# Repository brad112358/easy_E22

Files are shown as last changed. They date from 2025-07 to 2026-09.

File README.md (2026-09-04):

# Easy DIY E22 NRF52840 Build Instructions #

This project provides build instructions and 3D print files for a
basic but powerful DIY Meshtastic node with the following features:

- Pocket sized
- Battery powered, ~40 hour run time (Up to 2 weeks with double 18650 version)
- ~1 watt maximum output on internal battery power
- ~2 watt maximum output on USB power
- Based on two easy-to-obtain COTS modules
- Relatively easy assembly and soldering with no custom PCB required
- Optional GPS, OLED display, and Rotary encoder can be added for standalone operation

The castellated edge connections on the E22 module, along with the pin
assignment flexibility of the NRF52 MCU, allow most signals to pass
between boards with no wiring.  Just careful positioning, a little
solder, and three header pins connect all signals.  Point-to-point
wiring is used only for power and peripherals.

The E22 gives this node outstanding performance in a compact package
with longer range than most commercially available pocket nodes.
The hinged and swiveling antenna matches the physical design of the
node, shielding the battery power switch from accidental bumps.  This
node works well when folded, yet makes no compromises when
straightened up at your destination.

The core of this build can also be used in solar nodes; see the note in
step 11 and the techincal notes at the end.

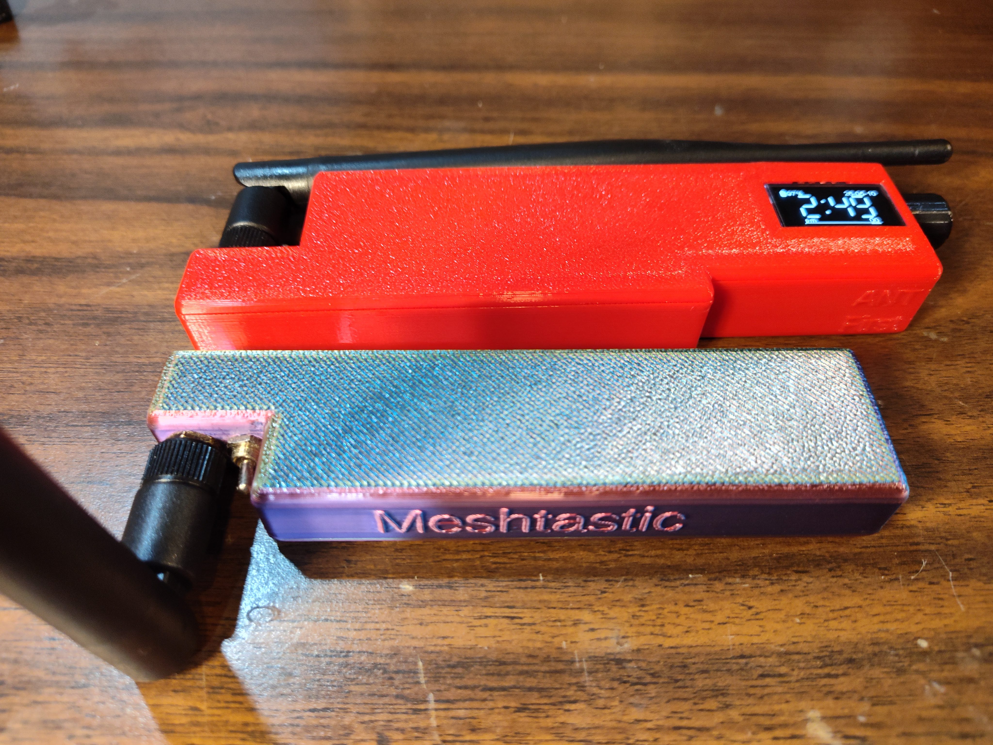
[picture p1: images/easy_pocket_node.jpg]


## Target audience

These instructions assume you have basic electronics soldering
equipment, supplies and tools, and are reasonably competent at
soldering surface mount and thru-hole PCBs.  If you have no experience
soldering, don't give up; you can probably learn to solder in a few
hours.  There are plenty of tutorial videos out there.  But don't do
your early practice on this project.

Similarly, it's best if you are familiar with other Meshtastic nodes
as this is not an introduction to Meshtastic.

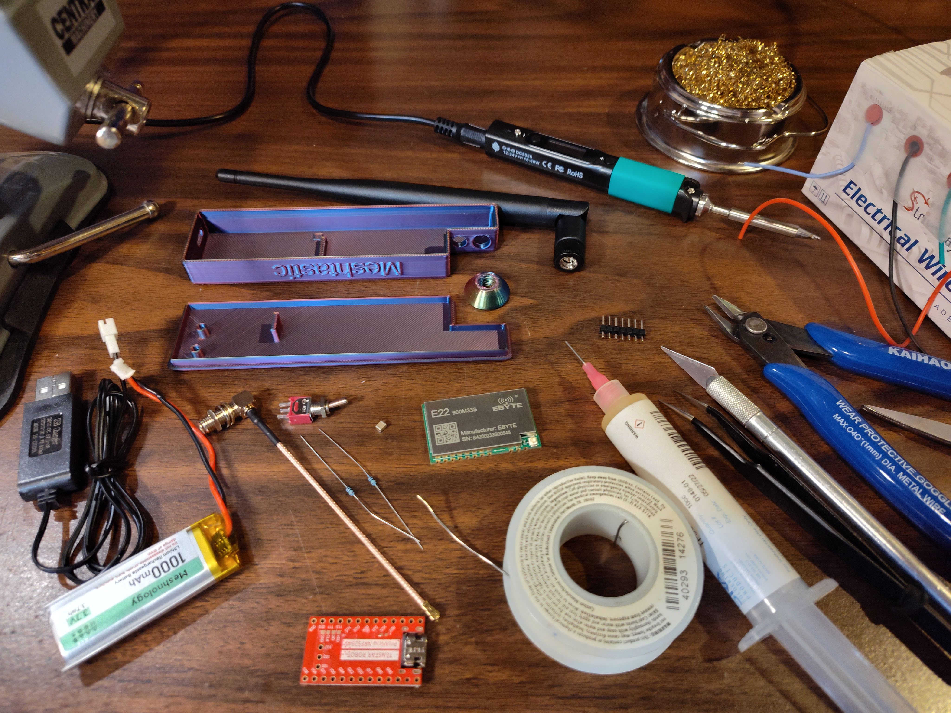
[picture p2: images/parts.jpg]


## Parts list:

Note: Product links are examples of components with the required
specifications and do not imply a recommendation of a specific part or
supplier.  These are not affiliate links.

- "Pro Micro compatible" NRF52840 dev module

    Such as the [Teyleten](https://www.amazon.com/dp/B0CYLNZ6V4), [Tenstar Robot](https://www.aliexpress.us/item/3256807958420169.html).
    Some of these can be found for less than $3 each.

- Ebyte E22 900M33S LoRa module

    Usually $15-20, available from [Amazon](https://www.amazon.com/868MHz-Wireless-E22-900M33S-Distance-Transceiver/dp/B0CZNHX91T) or [AliExpress](https://www.aliexpress.us/item/3256806595412116.html).
    
- 1000mAh LiPo cell with protection board or Li-ion 18650 cells

    The 50mm x 20mm x 10mm cells from
    [Amazon](https://www.amazon.com/dp/B0F1FM58ZW) or
    [AliExpress](https://www.aliexpress.us/item/3256802548578153.html)
    fits the smallest case design.

    Smaller cells can still provide useful battery life, but be sure
    they are capable of over 1 amp output without significant voltage
    drop.  Higher C cells will produce slightly higher RF output.
    You may also want a
    matching JST PH 2.0 socket like this one from
    [AliExpress](https://www.aliexpress.us/item/3256802377876396.html).
    
    You could try a [pre-made protected 18650 battery pack](https://www.amazon.com/GYMIN-Rechargeable-B0143KH9KG-18650-1s1p/dp/B0FRMR4ZHD).
    However, Amazon may not be the best source for high quality 18650 cells; so
    purchasing 18650 cells elsewhere is recommended if you want the
    best battery life.  You can use protected cells or, you can build
    your own battery pack with a [protection circuit](https://www.amazon.com/dp/B07W75BQWW) (recommended if
    you have experience building battery packs using a spot welder).

- Mini micro 3-pin SPDT toggle switch

    The battery switch needs to be smaller than is common; I used
    this one from
    [Amazon](https://www.amazon.com/dp/B075RDYMQQ) which is 8.2mm x 5.1mm
    and just fits.

- 915/868 MHz Antenna

    A high-quality hinged dipole fits and works well.
    
    Unfortunately, three out of three different brands I purchased
    from Amazon did not come close to high quality, and two of the
    three seemed to be less efficient multi-band antennas.
    
    The one that came with my Station G2 was close, needing only a
    slightly longer element to bring the resonant frequency down a bit
    from ~960 MHz.  The result looks very good now on the VNA.
    
    The ALFA Network ARS-915P from
    [ROKLAND](https://store.rokland.com/collections/all-helium-antennnas/products/alfa-network-ars-915pr-2-dbi-sma-male-915-mhz-antenna-with-90-elbow-for-t-beam-t-echo-lora32)
    Should be good quality for US use.

    When choosing antennas, be aware of the difference between SMA and
    RP-SMA.  It is, unfortunately, possible to attach an RP-SMA
    antenna to an SMA jack, but there will be no electrical connection,
    and you may damage the E22.  Always make sure you see a pin on
    one end or the other when connecting.

- SMA female right-angle 10 or 15cm Pigtail

    Like these from [Amazon](https://www.amazon.com/dp/B0F1R1FHK6)
    10cm may not be quite enough for the 2 18650 version of the case.
    
- Wire

    22-24 AWG stranded silicone wire is recommended for power
    connections to reduce voltage drop and keep RF power output up to
    spec.  30 AWG silicone wire works well for connecting the optional
    peripherals.

- Two battery sensing voltage divider resistors

    Almost any pair of the same value, axial-lead resistors will work to
    divide the battery voltage in half so that it can be measured
    safely by the ADC.
    10K - 1M ohm is recommended, as lower values may impact battery life.
    1/4 - 1/8 watt will work, but 1/8 watt is easier to fit.
    1% recommended, but up to 10% will work.
    You may need to adjust the ADC multiplier override ratio for
    accurate battery voltage readings, especially if you don't use 1%
    tolerance or choose a higher resistance than recommended.

- Common 2.54 mm pin header

    These usually come with the NRF52840 board.
    
- Heat-resistant insulating tape

    Every workbench should have a roll of this 
    [Stuff](https://www.amazon.com/ELEGOO-Polyimide-Temperature-Resistant-Multi-Sized/dp/B072Z92QZ2).
    Often called Kapton tape.

- Optional low power GPS module

    GPS modules only need power, ground, and two serial connections.
    [This one](https://www.amazon.com/dp/B09LQDG1HY) is relatively low
    power, fits well and has a small active antenna which fits well in
    the case.
    
- Optional passive buzzer/speaker

    A passive buzzer can be installed for (quiet) alert sounds
    and input feedback.
    [These](https://www.amazon.com/dp/B08MDNLDSV) were the lowest
    profile I could find and they just fit.

- Optional rotary encoder

    A small rotary encoder allows control via the Canned Message module.
    [These](https://www.amazon.com/dp/B07R8GKKX3) were the smallest I
    could find and fits well if the pins are bent carefully.
    
- Optional 1 inch OLED I2C display

    An OLED display is a good compromise with adequate visibility, low
    cost and reasonably low power.
    [These](https://www.amazon.com/dp/B09T6SJBV5) fit well on the lid
    of the case.
    
## E22 connections to NRF52 module

| E22 Pin Number | E22 Signal | NRF52 Pin | Method |
| --- | --- | --- | --- |
| 12 | GND | N/C | No connection |
| 13 | DIO1 | P0.29 | Direct solder |
| 14 | BUSY | P0.02 | Direct solder |
| 15 | NRST | P1.15 | Direct solder |
| 16 | MISO | P1.13 | Direct solder |
| 17 | MOSI | P1.11 | Direct solder |
| 18 | SCK | P1.10 | Direct solder |
| 19 | NSS | P1.09 | Direct solder |
| | | | |
| 11 | GND | GND | Header pin |
| 10 | VCC | B+ | Wire |
| | | | |
| 7 | TXEN | P1.00 | Header pin |
| 6 | RXEN | P0.11 | Header pin |

## Battery sense voltage divider connections

| NRF52 Pin | Battery sense voltage divider |
| --- | --- |
| P0.31 | R1 + R2 |
| B+ | R1 |
| GND | R2 |

## Power wiring

| Source | Function | Destination |
| --- | --- | --- |
| NRF52 pin B+ | Battery positive | Battery switch common |
| NRF52 pin GND | Ground | Battery negative |
| NRF52 5V USB | 5 volts | Battery switch off |
| Battery switch on | Battery | Battery positive |

## NRF52 module optional feature pin mappings

| Pin   | Function    |
| ----- | --- |
| P0.06 | Button Opt  |
| P0.08 | Buzzer      |
|       |             |
| P0.20 | Rotary B    |
| P0.22 | Rotary A    |
| P0.24 | Rotary press|
|       |             |
| P1.04 | SDA         |
| P1.06 | SCL         |
|       |             |
| P1.02 | GPS RX      |
| P1.07 | GPS_TX      |

## Build procedure

Instead of a custom PCB, the castellated edge of the E22 module
is soldered on the insulated back of the NRF52 module.
Construction time may be 1-2 hours for the basic node or 3-6 hours for
a node with a display and 18650 battery pack.

When soldering the castellated edge, be sure *not* to solder
pin 12 of the E22 module.
It's an unused ground, and the corresponding pad of the NRF52 module
will be used for the battery sense voltage divider.

Strip and tin each wire before soldering it in place.

### 1. 3D print or obtain a case

The OpenSCAD source and STL files are included here.  Print the
case.stl file for the basic light weight/compact design.  Print one of
the 18650 files if you plan to use one or two protected 18650 cells
for longer battery life.  Otherwise, if you want a display, use the
display*.stl files.  The OpenSCAD source is included if you want to
modify the case.  If you don't have a 3D printer or a friend with one,
some public libraries have them.  There are also companies that sell
this service.

PLA works great, though PETG or ABS/ASA is better if your node might be
left in a vehicle or otherwise exposed to heat.  Use your highest
strength settings.  Supports should not be required.  Test fit the
cover after printing.  It should snap on tightly.

### 2. Flash firmware

Be sure to perform the initial flash of the firmware on the NRF board
before proceeding with the assembly, so that the debug pads on the
bottom of the board will be available in case anything goes wrong.
This also ensures that the TXEN pad is not driven when it shouldn't be,
which could damage the E22.

#### Update Bootloader

Follow the Meshtastic instructions to upgrade to the
[Adafruit bootloader](https://github.com/adafruit/Adafruit_nRF52_Bootloader) using
[Method 1: UF2](https://meshtastic.org/docs/getting-started/flashing-firmware/nrf52/update-nrf52-bootloader/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).
Download and install the
[latest version](https://github.com/adafruit/Adafruit_nRF52_Bootloader/releases/latest)
of the update nice nano bootloader,
e.g., `update-nice_nano_bootloader-0.9.2_nosd.uf2`.
If you may later want to use OTA firmware updates, flash the bootloader
included [here](update-promicro_nrf52840_bootloader-0.9.2-otafix1_nosd.uf2) instead.

Note that since there is no reset button, you need to carefully and
briefly short the RST to any convienent GND like the pad next to RST
or the USB housing twice within 1/2 second to activate bootloader mode
after connecting the USB port to your computer.  Be sure you short
only the correct pin, 4th from the USB end.  A Small tweezers or a
stiff wire or even the leads of a multimeter set to measure current
works well .  It may take more than one try; look for the red LED to
remain off or slow "breathing" to show success.

#### Install or Update Meshtastic

Once the bootloader is installed, you can use the same method to
install the Meshtastic firmware.  I have provided an older
[firmware binary](firmware.uf2), but it is probably best to build the
latest firmware using github workflow actions.

Meshtastic does not release pre-compiled firmware for this node, but
you don't need to setup a full development environment to build the
latest meshtastic firmware.  Instead, you can use github workflow
actions to build the firmware from your own fork on github.  Currently
only the develop branch and v2.8.0.* tags include support for this
node.

To build the firmware on github:

- Login to your personal github account and go to (meshtastic/firmware)[https://github.com/meshtastic/firmware]

- Create your own fork by selecting "create a new fork" from the "Fork"
  dropdown menu.  Be sure to Uncheck "Copy the develop branch only"
  
- FYI: Since the github web interface only supports syncing existing
  branches, if you later want to build a tag or branch that didn't
  exist when you created the fork, you may need to first delete your
  fork.  This can be done under Settings -> Danger Zone on your github
  fork.  There are ways around this if you are a git command line
  user.

- Click "Actions" at the top of your new branch main page and enable workflows

- Select "Build One Target" and click on the dropdown "Run workflow" menu

- Click on the "Branch:" dropdown and select the Branch or Tag you
  wish to build;  A stable or beta tag is recommended
  
- Enter "nrf52_promicro_diy-easypromicro" into the target board field
  and click "Run workfloww"
  
- You should eventually see the job status change to "Success" which may take several
  minutes or even a few hours depending on how busy the github workflow runners are
  
- Refresh the page in your web browser to show the build job Artifacts

- Download the largest artifact which is a zip file containing .uf2
  files for the firmware and factory erase images and an ota zip file.
  
- Unpack the downloaded zip file and flash the firmware-nrf52-easypromicro*.uf2
  file using the same method used to flash the bootloader above.

After everything is succesfully flashed, unplug and plug in just the
NRF board into USB power and verify you can pair and connect to it
with the Meshtastic app.

### 3. Set battery charge current

If you will connect a battery larger than about 500 mAh, you probably
want to short the two square "BOOST" pads on the back of the board
near the RST and VCC pads to increase the charge current and reduce
charge time; Solder stripped wire-wrap wire, or separate a couple of
coarse wire strands, or just bridge the pads with solder, keeping it
as thin as you can.

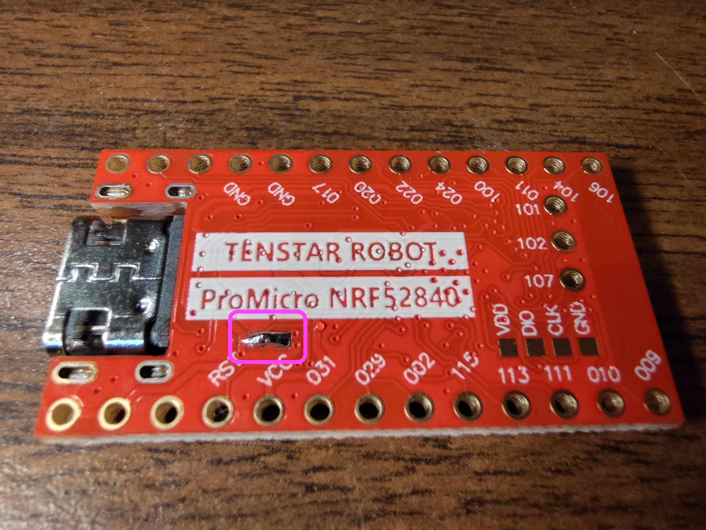
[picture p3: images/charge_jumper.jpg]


### 4. Insulate boards

A layer or two of polyimide or other high-temperature tape between the
boards is recommended to avoid any chance of shorting exposed vias.
Leave the E22 pads on the edge with VCC exposed, but cover the back
surface of the pads on the other edge.

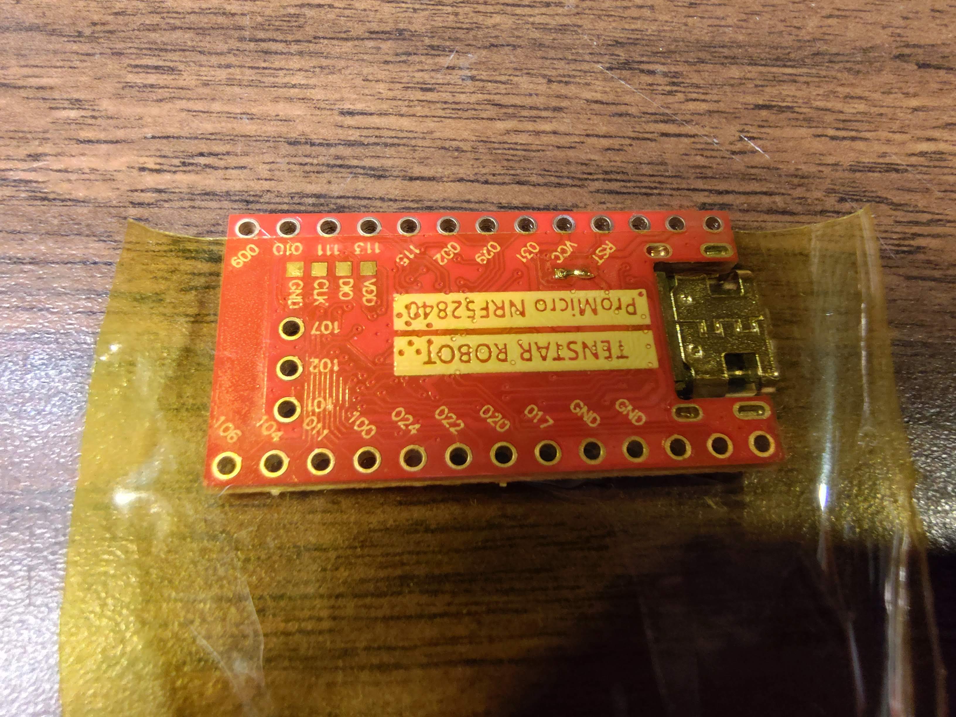
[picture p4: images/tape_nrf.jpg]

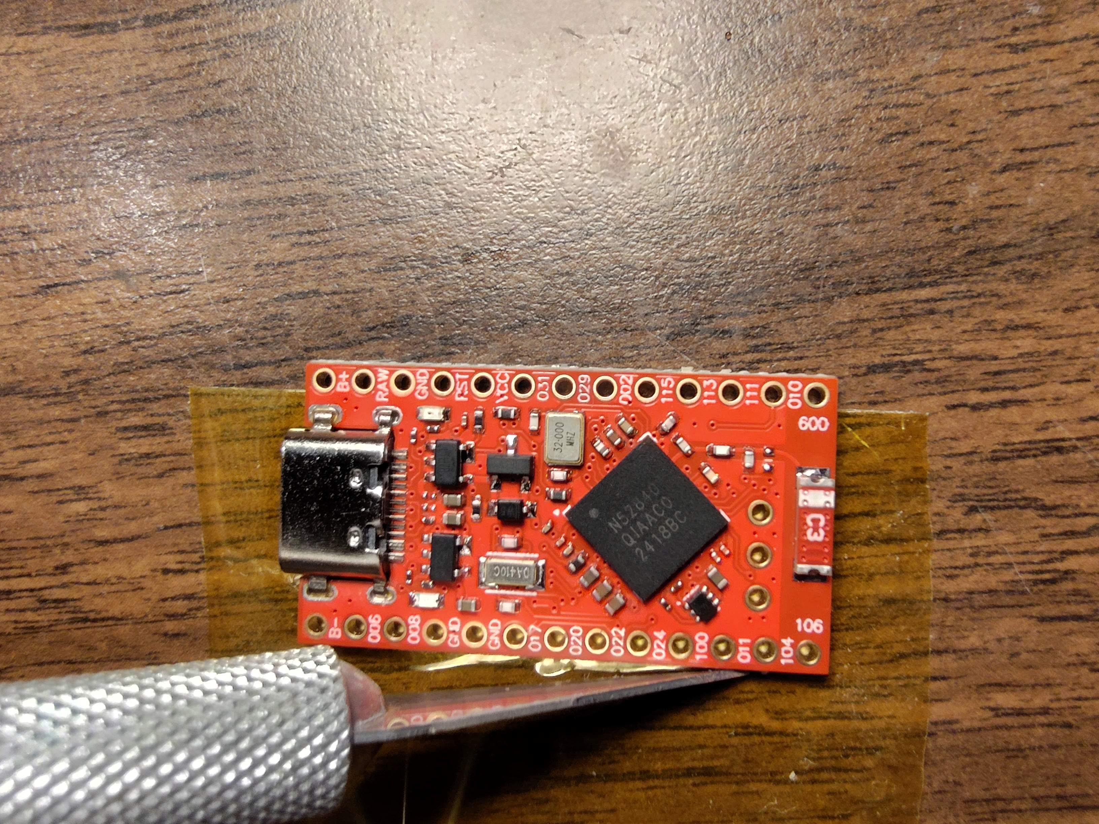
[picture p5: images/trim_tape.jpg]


Cover the entire pin 12 GND pad next to DI01 on the E22 to avoid any
chance of shorts when the resistors are later installed.

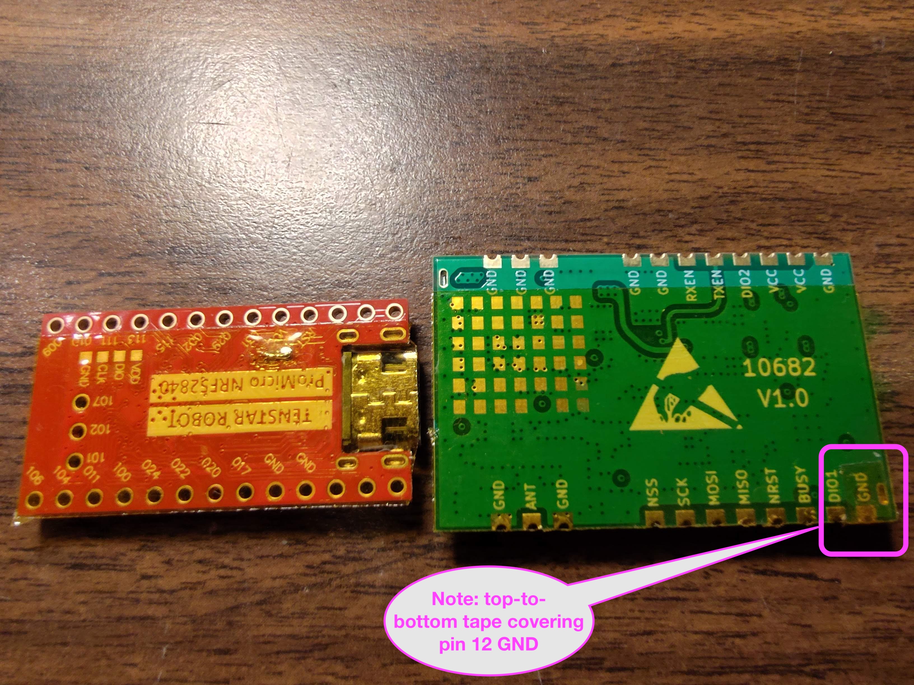
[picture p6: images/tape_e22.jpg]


### 5. Align and very gently clamp boards

After applying and trimming the heat-resistant tape, position the
boards back to back, such that pads
P0.09-P0.29 on the Pro Micro NRF52840 line up with
pads NSS-DI01 (pins 19-13) on the E22. Align the boards carefully such that
last eight pads on each board are directly opposite, but not quite touching.

> ⚠️ **Warning:** Only seven of the eight aligned pads will be bridged,
so the NRF board should overhang the E22 enough that you can
see the entirety of each pad on the bottom of the NRF board.

Hold or very gently clamp using rubber bumpers the boards in this position.

If you position the boards carefully, with ~.1mm gap between the inner
edges of the pads on the NRF and the castellated edge of the E22, you can
make the connections with solder bridges and still easily unsolder them to
separate the boards later in case you brick it and need to access the
programming pads on the bottom.

If you are manually holding the boards in place, it helps to apply
solder to a central pad on both boards before you position them so you
can make the first connection with out needing a third hand.  After
that, you can set the boards down to finish the other six connections.

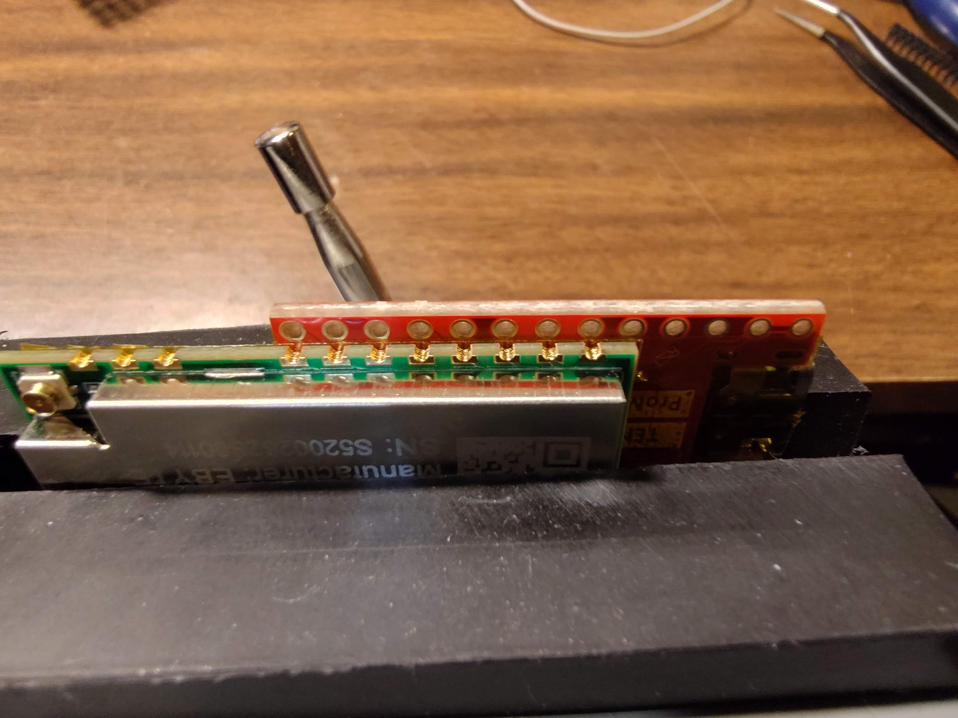
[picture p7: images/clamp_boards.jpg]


### 6. Solder first edge connections

Start by soldering the two connections on each end, 009 to NSS and 029
to DI01.  Solder from the NRF board bottom pad to the edge of the
corresponding castellated E22 pad.  Before proceeding to solder the 5
remaining connections on this edge of the boards, check that the
spacing is correct and that each connection is correct as in the table
above.

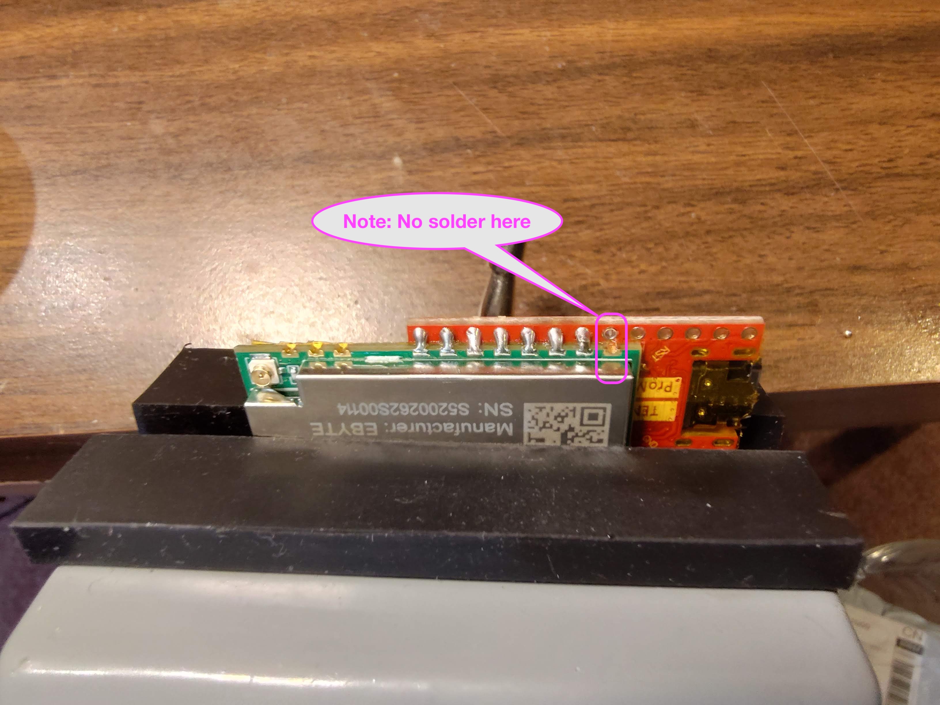
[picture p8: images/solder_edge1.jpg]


### 7. Install voltage divider resistors

For battery-powered builds, you will want a voltage divider to sense
the battery voltage.  Solder a resistor between P0.31 and B+ or RAW
and an identical resistor between P0.31 and GND on either side of the
board.

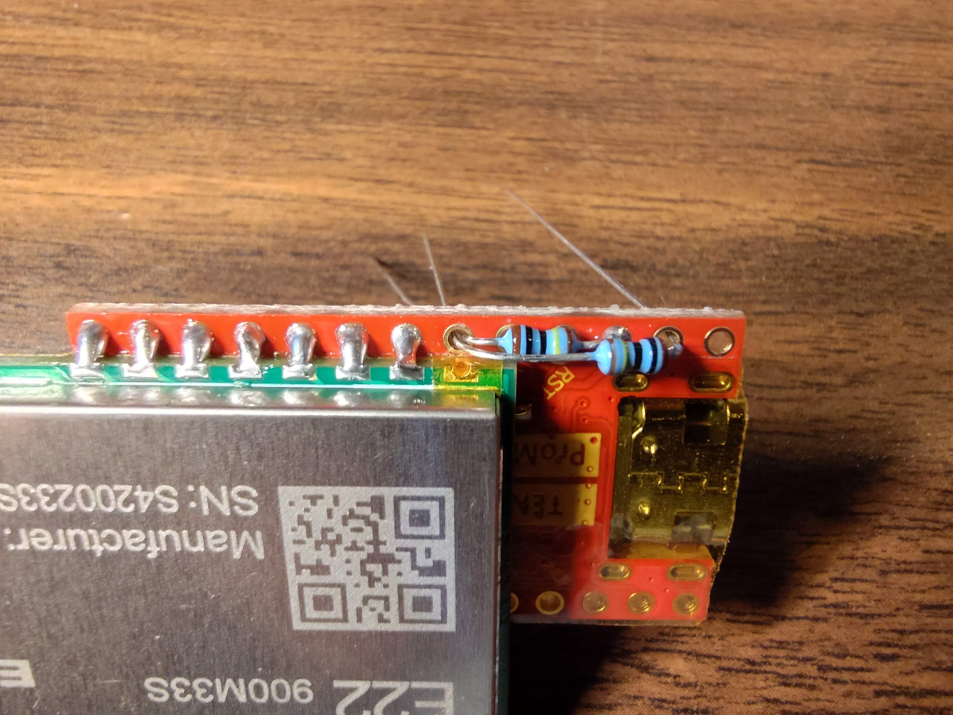
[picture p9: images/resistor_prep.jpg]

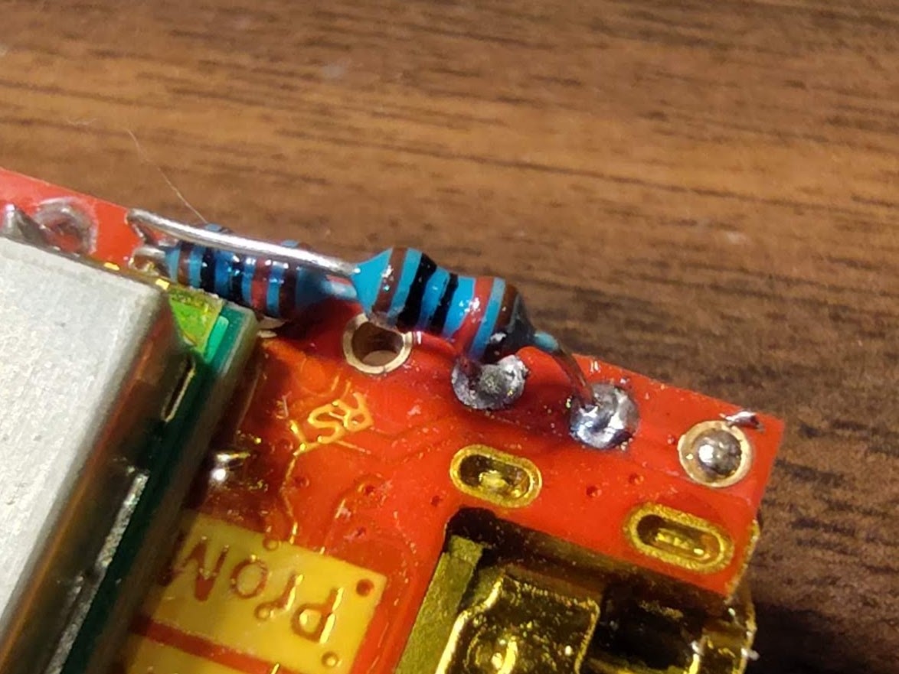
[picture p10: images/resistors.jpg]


### 8. Optional capacitor

To reduce power supply noise, you can also solder a ceramic SMD
capacitor between the VCC and GND pads on the E22.  Note that while
this is best practice in general and the E22 data sheet recommends
filter capacitors, it does not specify a required value and it is
probably OK to leave this out.

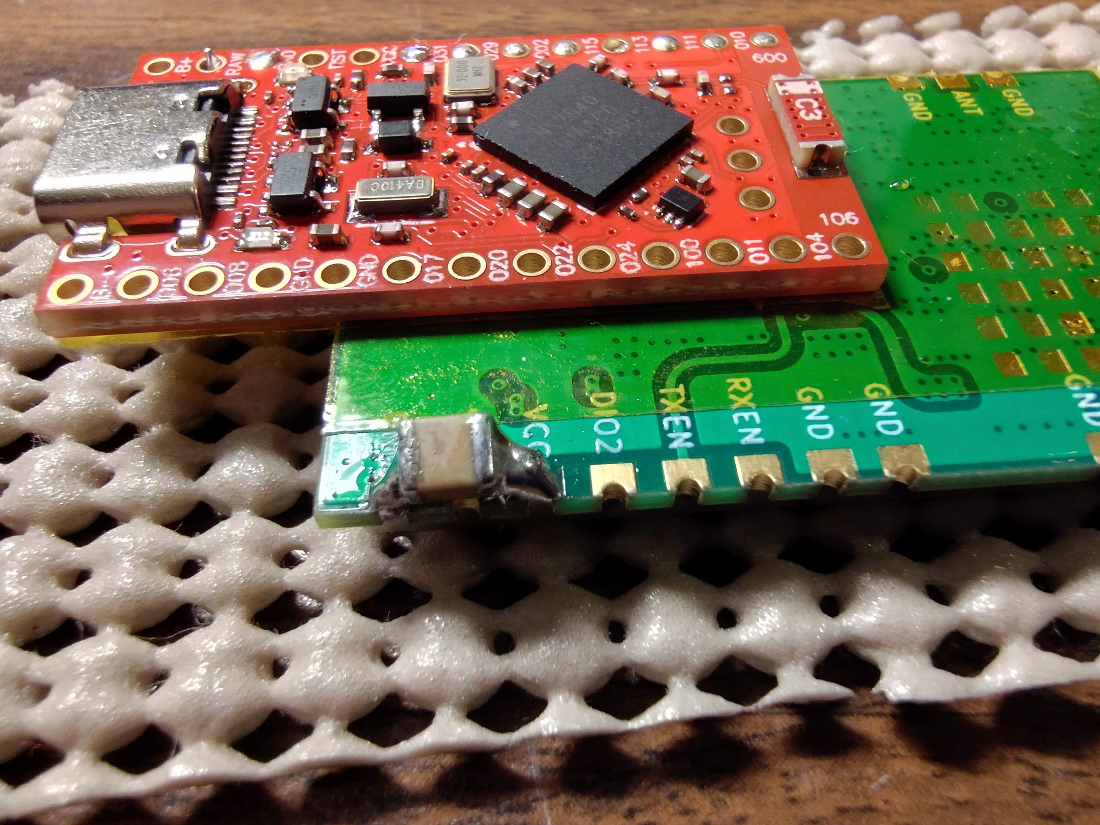
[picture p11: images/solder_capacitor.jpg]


### 9. Solder second edge connections

On the other edge of the boards, solder short solid conductors from
RXEN to P0.11, from TXEN to P1.00, and from GND to GND.  Notice the
GND connection is offset by one position so it will be at a slight
angle relative to the other pins which are straight across.
Insulation is not needed here, but the use of trimmed header pins is
recommended.  The rigid pins help hold the boards together and reduce
the chance of breaking solder connections on the first edge.

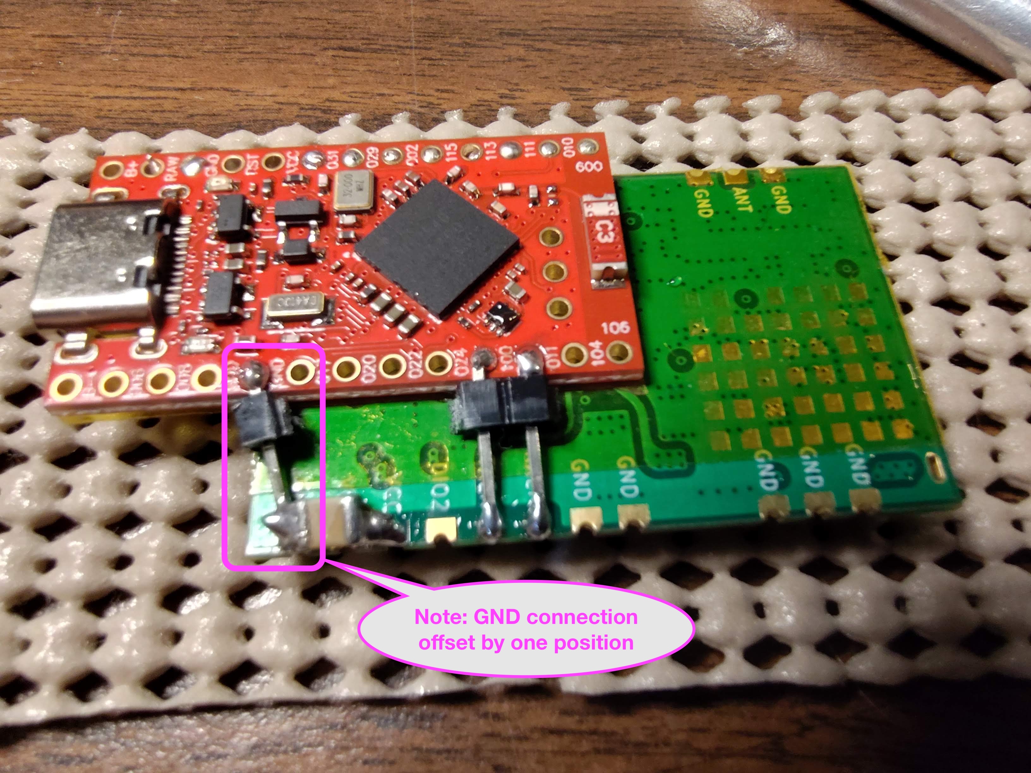
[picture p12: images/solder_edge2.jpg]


### 10. Solder power wire

Next, we need to connect the E22 VCC; Solder a short length of
insulated wire from VCC on the E22 to the B+ or RAW pad.

> ⚠️ **Warning:** Never connect USB or power up the E22 without an
antenna or 50-ohm load connected, or it may be damaged.  And never set
SX126X_MAX_POWER define to more than 8 when building firmware for the
E22 900M33S, or it will be damaged.

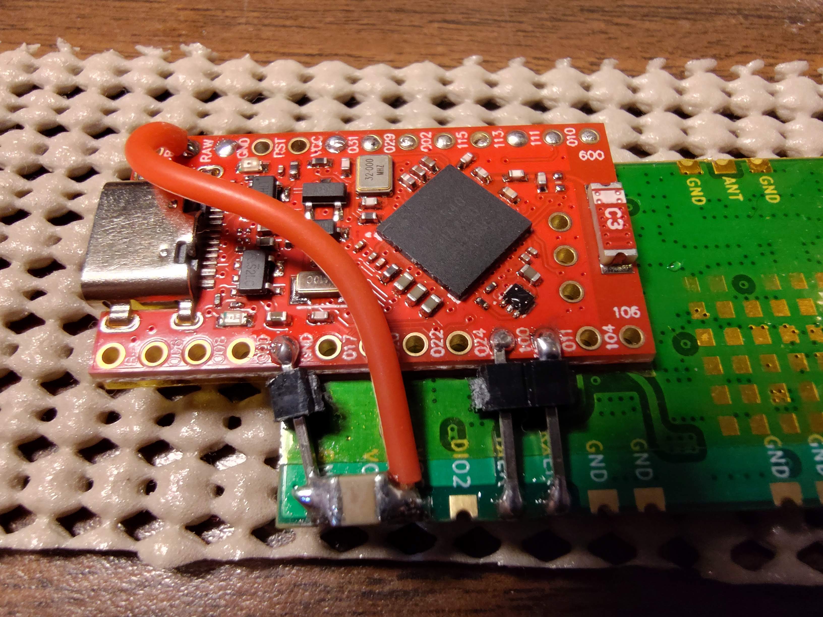
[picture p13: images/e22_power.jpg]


### 11. Check work

Use a continuity tester to carefully check each soldered connection
and also check for any unintended shorts between adjacent pads.

Test fit the board in the case with the USB connector level and
inserted into the USB hole.  Then, gently press the boards down to
seat the edge of the E22 RF shield against the wall in the middle of
the case so it can't slide away from the USB hole.  If the USB
connector won't fit the hole because of filament sag, carefully trim
to fit.  If the boards won't easily fit down against the wall so that
the RF shield is flat against the bottom of the case,
carefully remove some material from the wall with a sharp knife or
file.  If the USB connector is not held firmly in place in the USB
hole, add a layer or two of tape to the wall.

Note: If you plan to use this in a 1 or 2 watt output solar node
without GPS, you are essentially done with construction of the core
part of the node at this point.  I don't provide complete build
instructions for a solar node here, but you may want to review the
remainder of this document for configuration and other useful
information.  A 1 watt output solar node could be powered by a
protected Li battery connected directly to the B+ or raw pad and
charged by a 5 volt regulated panel connected to the USB port or the
LDO pin mentioned in section 15.  Or, a 2 W node could be constructed
by connecting the 5 volt output of a more efficient MPPT charge
controller with battery to B+ or raw.

### 12. Wire battery switch

Clip all three terminals of the battery switch so they are a bit shorter than
the original length of the outside two terminals, and test fit it in the case.

Solder wires to the two farthest terminals, closest to the SMA.

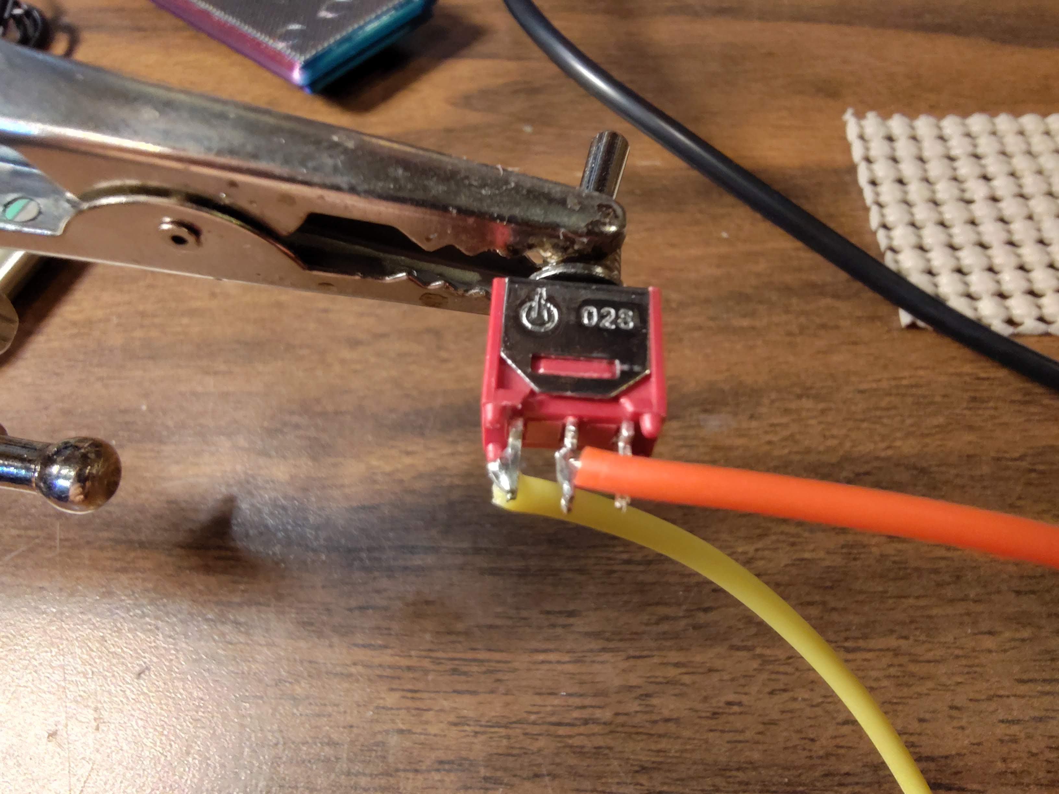
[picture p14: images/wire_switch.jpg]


### 13. Install SMA pigtail

Use a nut or a few washers inside the case to adjust the exposed length of the SMA jack so
that the antenna fits properly.  Tighten the nut snugly while holding
the jack so the pigtail touches the bottom of the case where it
connects to the SMA jack to allow room for the battery switch.  Test fit the
antenna;  it should get tight just before it reaches the nut.  If it
contacts the nut first, adjust the inside spacing.

Carefully connect the pigtail U.FL to the E22, and be careful not to
pull or twist it off during the remainder of the assembly.

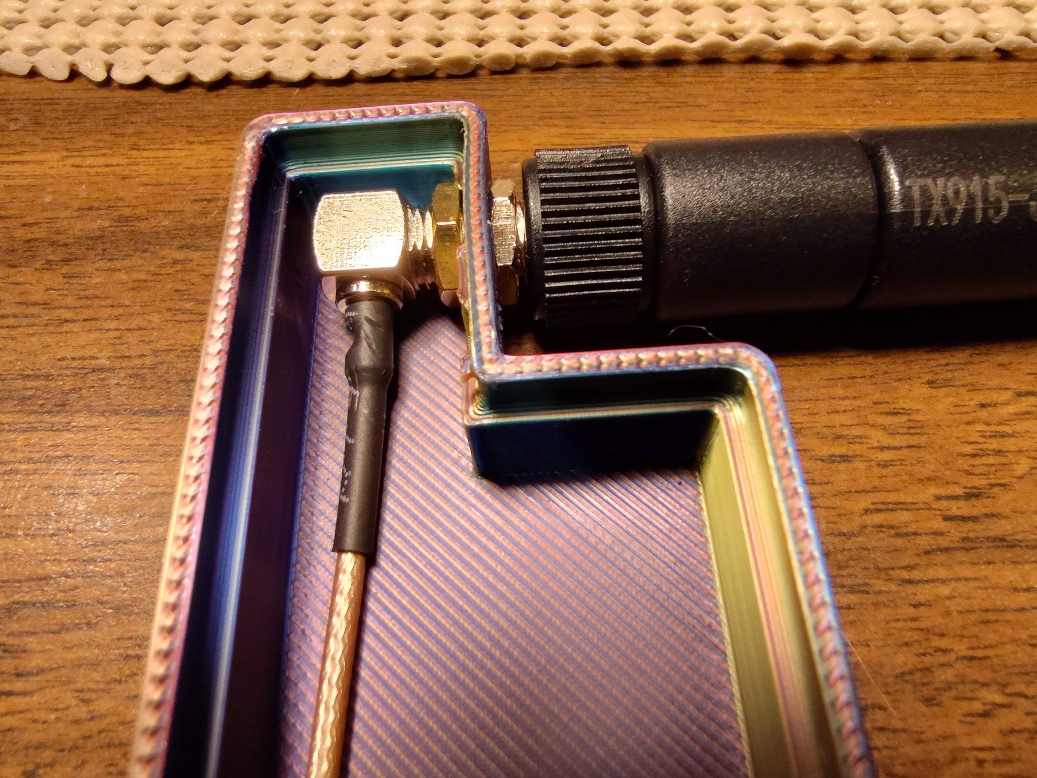
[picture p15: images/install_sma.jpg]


### 14. Connect Antenna or 50-ohm load

Never power up the E22 or connect the USB without an antenna or load
connected or it may be damaged.

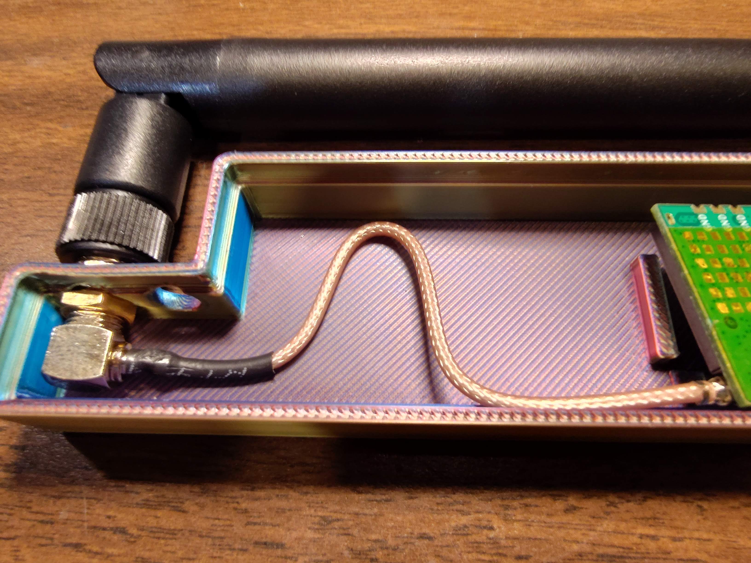
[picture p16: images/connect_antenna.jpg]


As you make the remaining connections, place the boards and battery switch in
position and trim wires close to the required length so they will fit
neatly in the case.

### 15. Connect battery switch and battery wires

Solder the wire on the battery switch terminal closest to the SMA to
one of the LDO terminals, which are connected to the USB VBUS pads
(You can leave this off if you don't want the option of higher power.)
Unfortunately, USB power is not connected to a pad on this board.
But, it is easy to use a continuity tester to find a convenient LDO
pin that connects to the USB power pins.  The USB VBUS pads are the larger
pads second from either end of the USB connector.

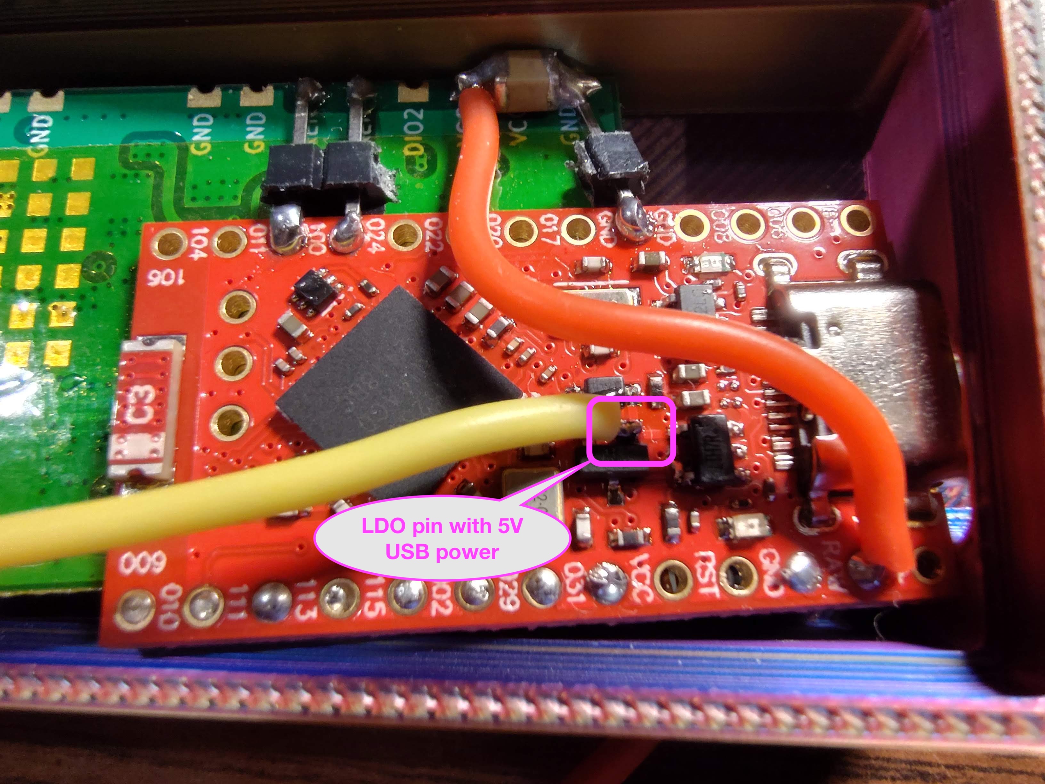
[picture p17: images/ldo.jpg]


Move the battery switch toggle to the off position, closest to the case.

Connect the wire from the middle battery switch terminal to the B+ or raw pad,
or to the VCC pads of the E22.

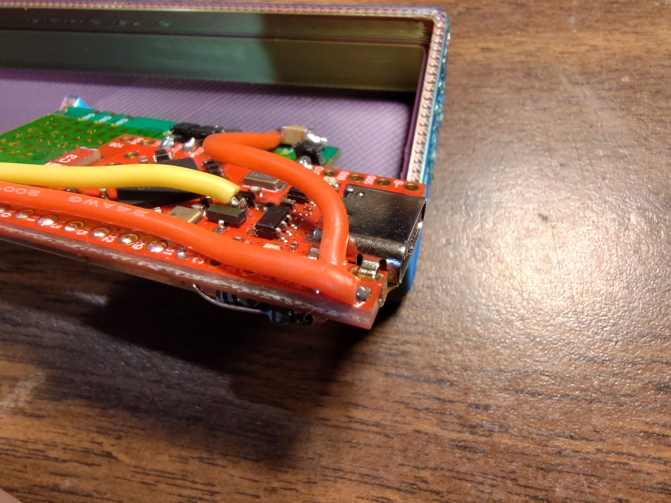
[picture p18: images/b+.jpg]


If you don't have a jack to fit the battery connector, and you don't
need the battery charger that may have come with the battery, you can
use its jack and wire for the battery connection.  Or, you may
carefully solder the battery lead directly if you don't want the
battery to be removable.

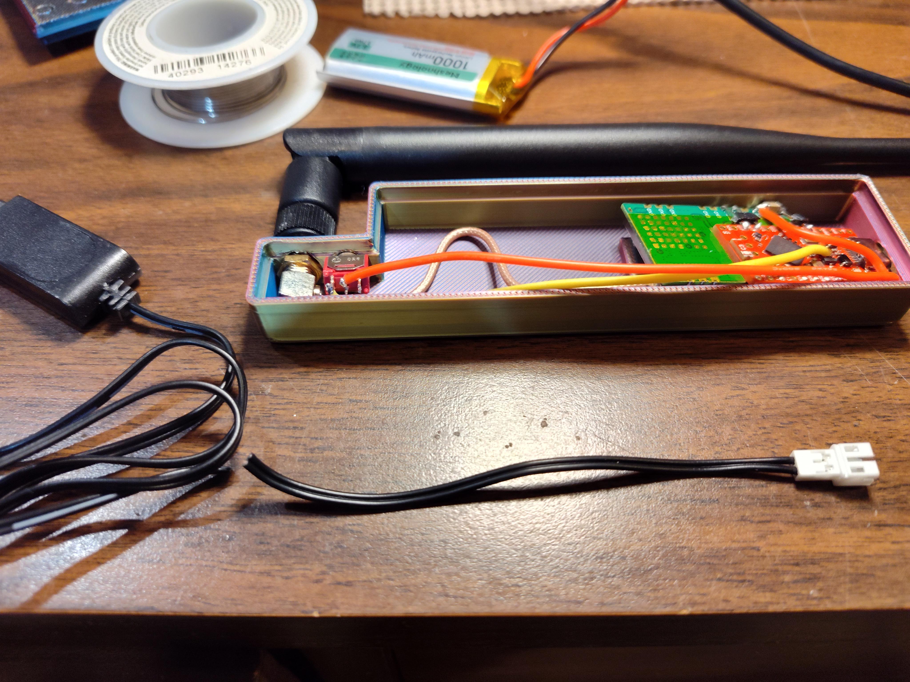
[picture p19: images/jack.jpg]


#### If you will power your node from a LiPo cell or a Li-ion pack:

Connect the remaining (closest) battery switch terminal to the positive (red) battery lead
or the correct battery jack wire.

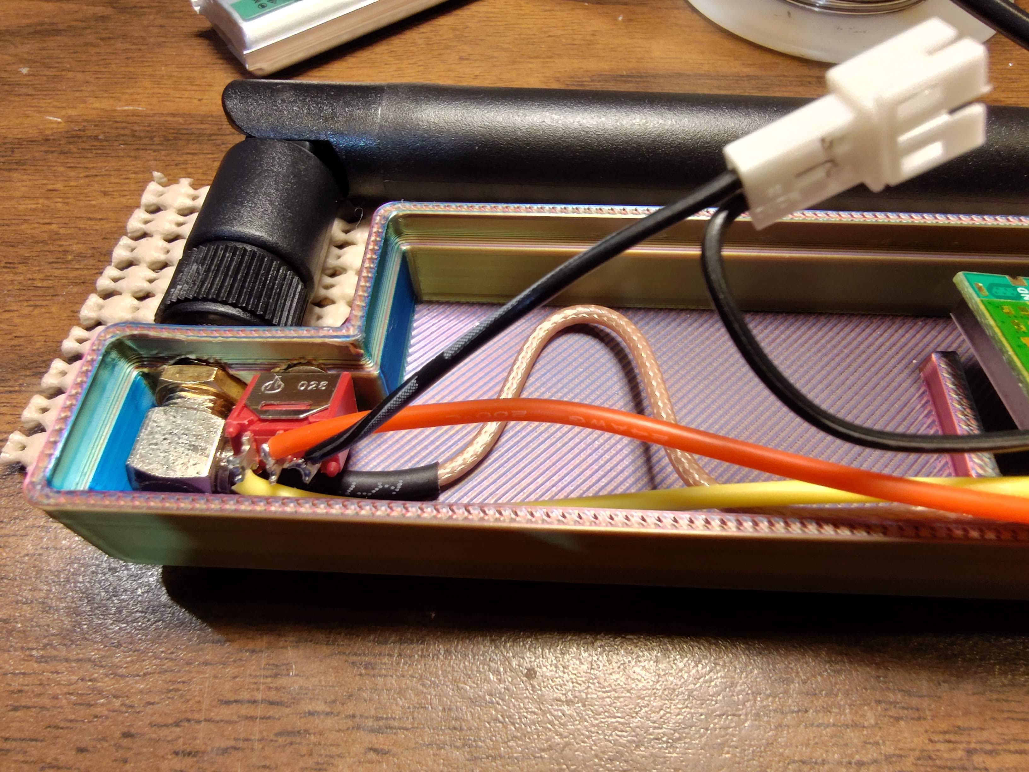
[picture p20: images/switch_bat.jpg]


If you purchase a protected 1S2P battery, you may need to remove or
reform the heat shrink wrapper to use the existing case design which
is intended to fit the cylindrical cells.

If you have access to a battery spot welder (soldering directly to
18650 cells is not recommended), you can build your own high capacity
3.7 volt 18650 1S 2P pack for a more reliable connection than the
removable cell method below.  Be sure to include a battery protection
board if you use unprotected cells.

Insulate the positive terminals with paper disks or heat resistant
tape before spot welding .2mm Nickel strips on both ends; positive to
positive and negative to negative to form a 1S 2P pack.  Be sure to keep
the cells perfectly parallel to each other with no gap as the case
does not have extra room.  Use additional heat resistant tape where
the positive terminals of the protection circuit will go.

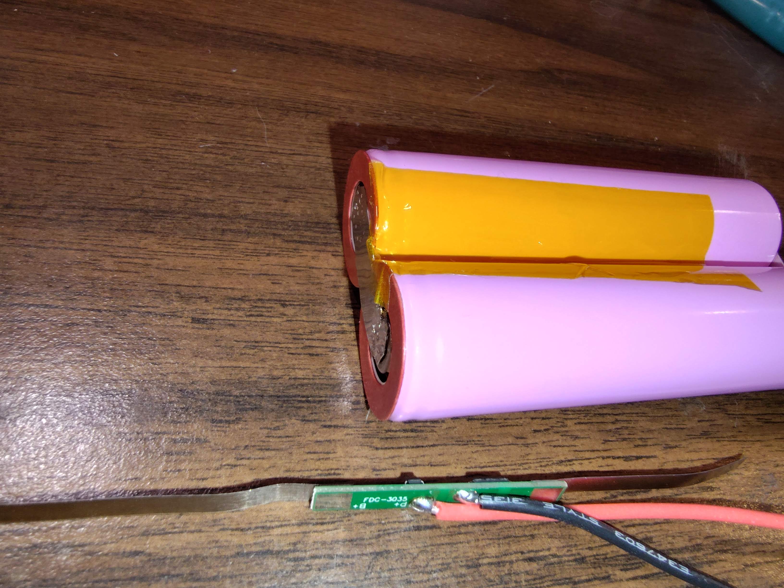
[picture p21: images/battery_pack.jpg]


Solder the wires to the battery protection circuit before welding its
tabs over the top of the welded Nickel strips.  Observe correct
polarity everywhere.

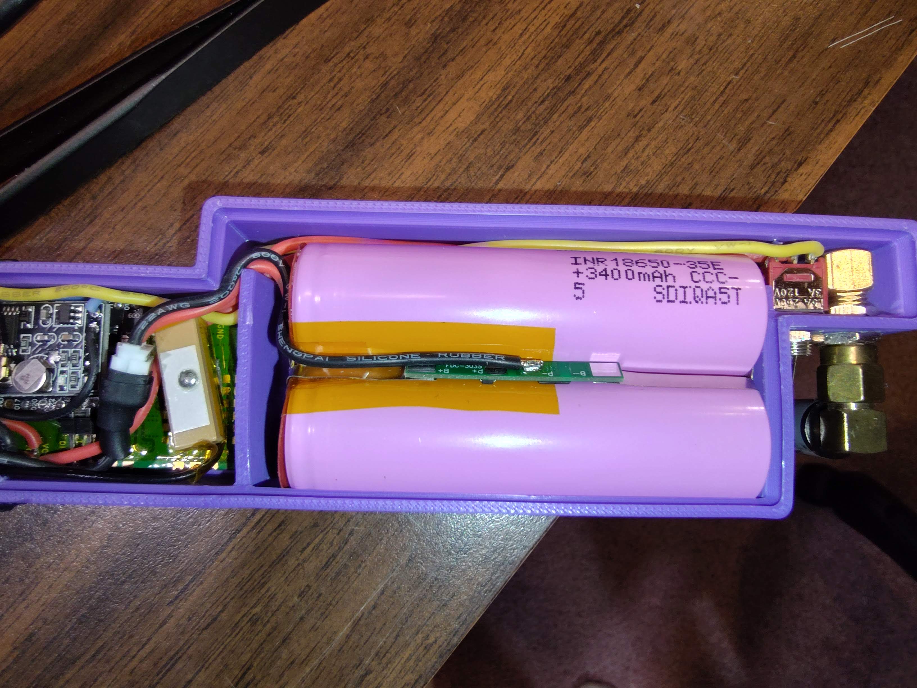
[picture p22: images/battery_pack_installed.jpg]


#### If you will power your node from one or two removable protected 18650 Li-Ion cells:

This method can be fiddly and less reliable than a protected battery
pack with a connector as above especially if the node is left in a hot
environment, but it uses easy to find protected cells and requires no
battery pack construction.

Fashion battery holder contact pads from a thin piece of shiny metal
which will take solder.  I cut small pieces of .2mm Nickel battery
welding strip, but a piece cut from the lid of a tin can might also
work.

Once you determine where the contact pads will be mounted, test
fit the pads with the battery.  Solder wire to each contact pad in a location
where it will not get caught when the battery is installed.  You
can use double sided adhesive foam mounting tape to mount the battery contact pads in
the battery holder section of the case.

When installing the battery for the first time, work slowly to allow
the foam tape to compress and be careful not to apply too much
pressure at the negative contact wall; this part is easy to snap off.
If the battery does not fit snugly, add a second layer of mounting
tape.  If it is too tight, use less mounting tape.  If the battery
does not make solid electrical contact at the negative side, you can
add a bit of solder to create a bump near the middle.

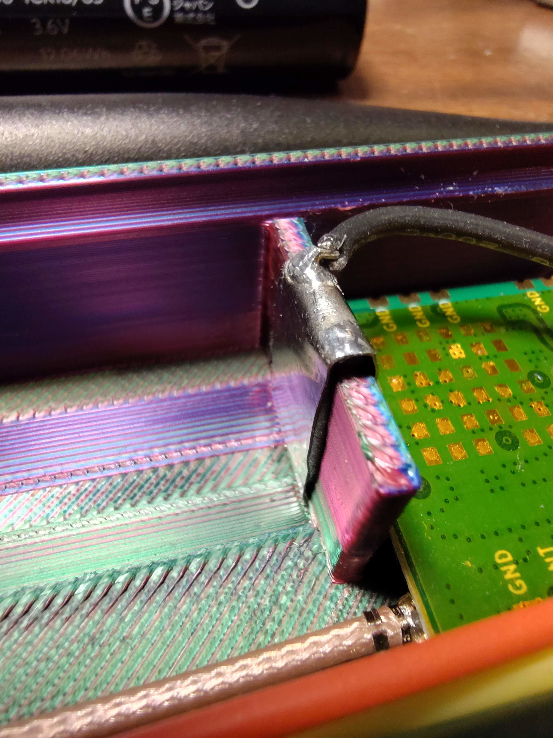
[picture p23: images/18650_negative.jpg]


Connect the remaining (closest) battery switch terminal to the
positive contact pad at the switch end of the case.

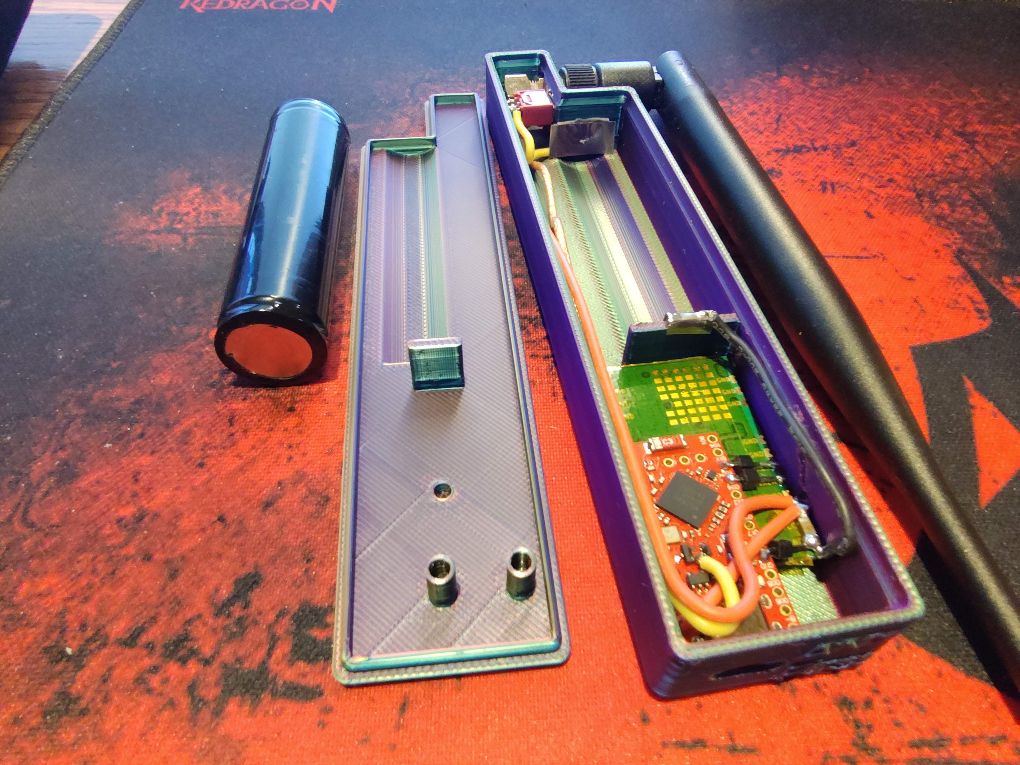
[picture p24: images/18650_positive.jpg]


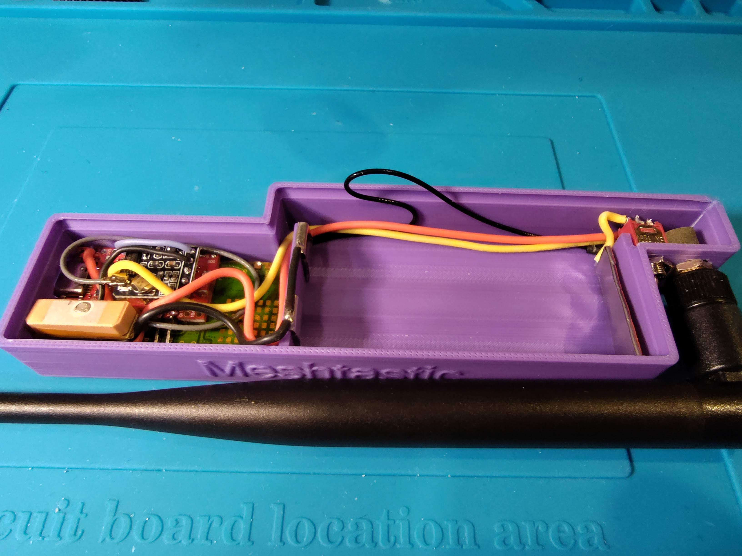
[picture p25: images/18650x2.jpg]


### 16. Install battery switch

Tighten the battery switch nut snugly while preventing the switch from
rotating.

The off position of the battery switch is towards the case, and the on position
is towards the SMA jack.  Note, however, that the node will also be
powered on when the switch is off if USB power is connected.

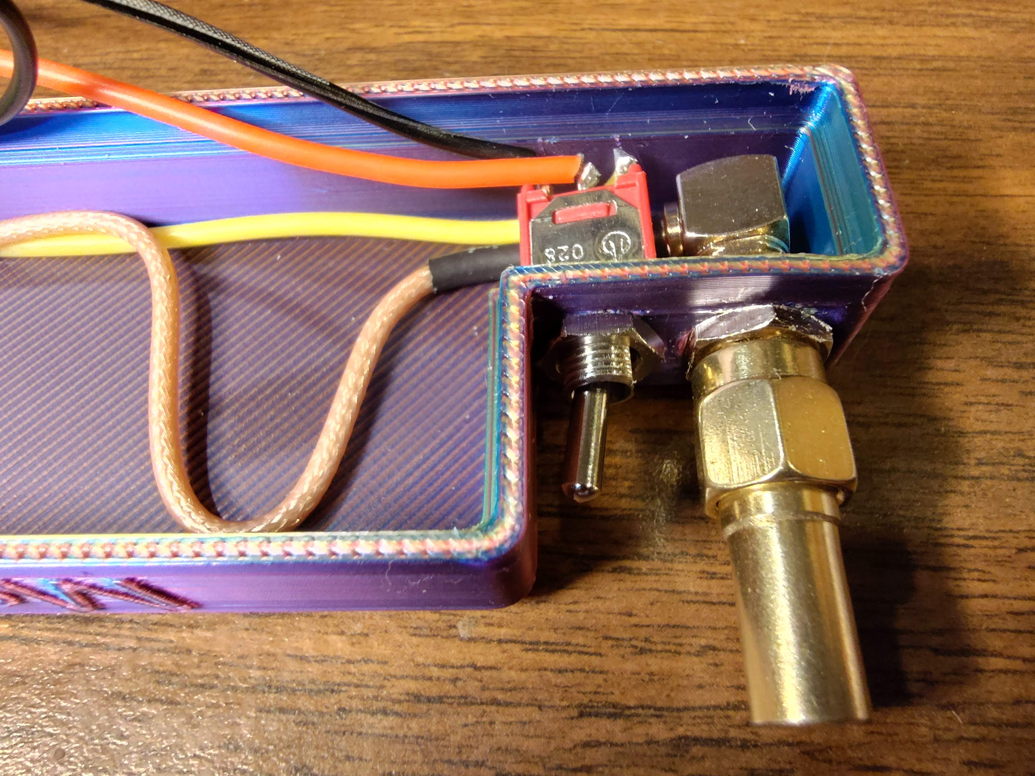
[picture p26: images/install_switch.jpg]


### 17. Install battery

Check that the battery switch is in the off position and that the antenna and
U.FL are still connected.

Solder the negative (black) lead of the battery, contact, or jack wire to a GND
pad.

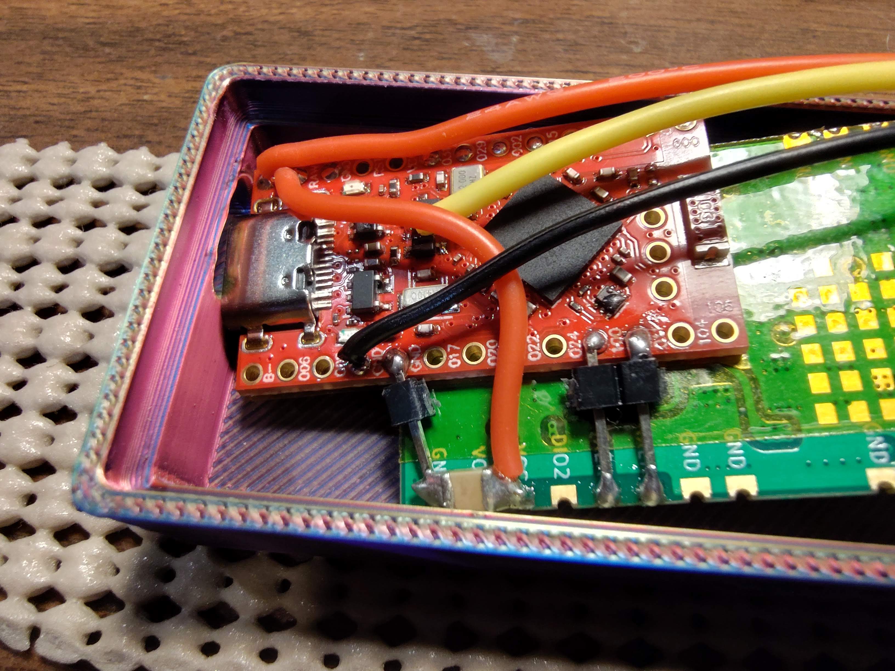
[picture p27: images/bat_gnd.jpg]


If you used a connector for the battery, connect it.
Arrange wires and place the battery in the case.
Hints for 18650 cells:  Install the one on the longest side
first.  It may be easier to insert the positive end of cells first.
Observe battery polarity, there is no reverse voltage protection!

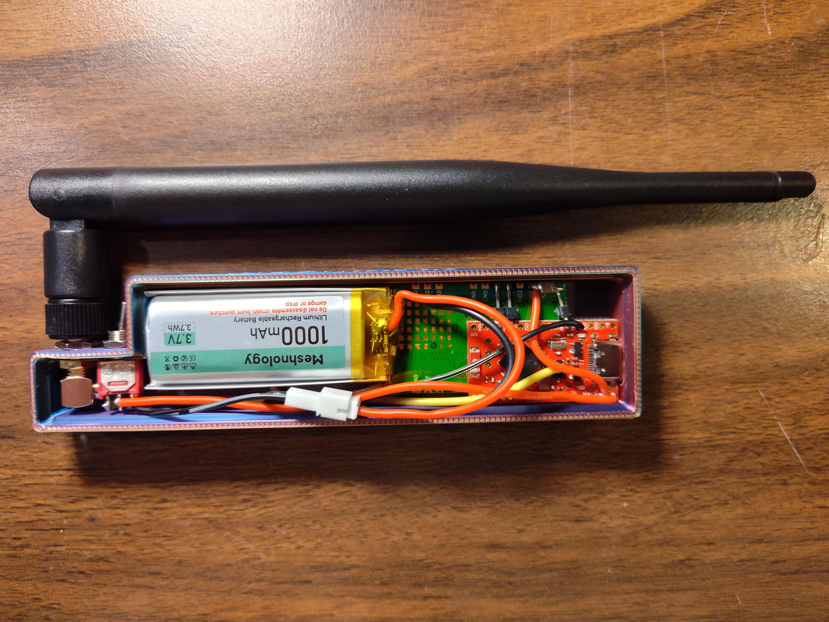
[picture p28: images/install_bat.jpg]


### 18. Optional GPS

When used with a mobile device, no GPS is needed as the mobile device
can be configured to provide it's location.  If, however, you want to use
this node as a tracker, a GPS can easily be added.

The NRF52840 dev module includes a switched 3.3V power output which we
take advantage of to extend battery life by powering the GPS module
only when needed.  When the GPS is enabled, battery life will be
reduced, especially inside buildings where a fix is harder to obtain.
You can still expect the battery recommended here to last a full day.

If you use the recommended GPS module or one with the same form factor
and pin out, you can connect the Rx and Tx pads via header pins and use
wires only for power and ground.  If you use a different GPS module,
be sure to connect Rx to Tx and Tx to Rx.

First, solder two header pins, long side down to the P1.02 and P1.07
thru holes on the NRF52840 module and then remove the plastic spacers.

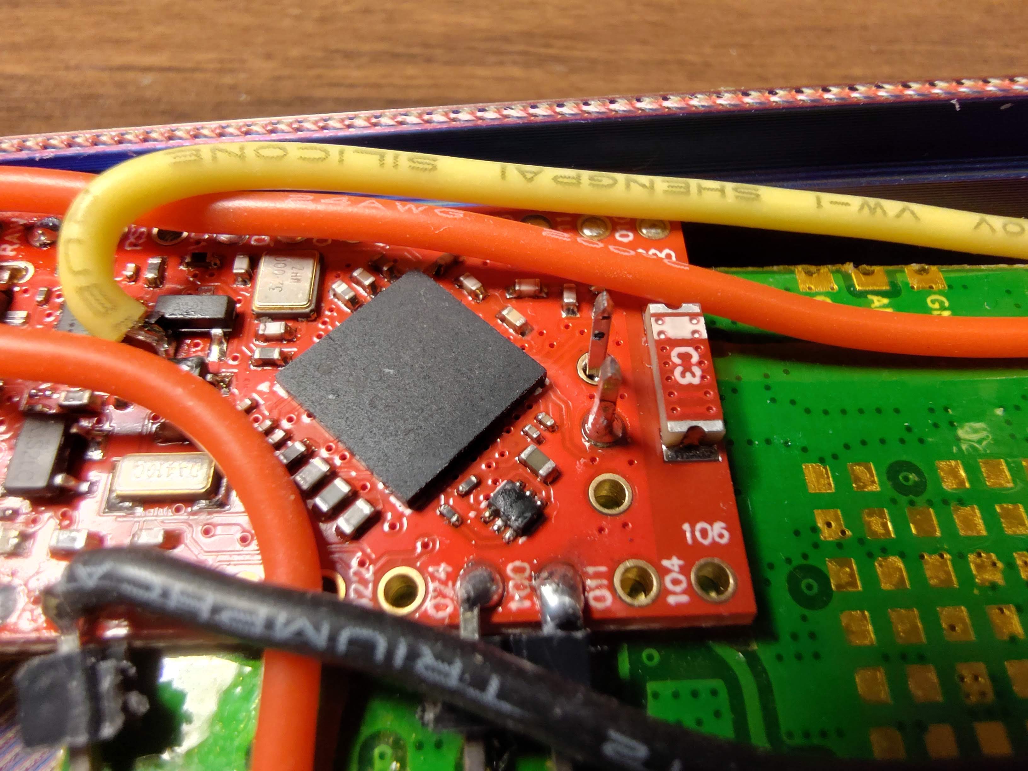
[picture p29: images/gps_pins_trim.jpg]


Trim the pins to fit the GPS module and place it on the pins with it's
metal shield flat against the NRF chip as shown.

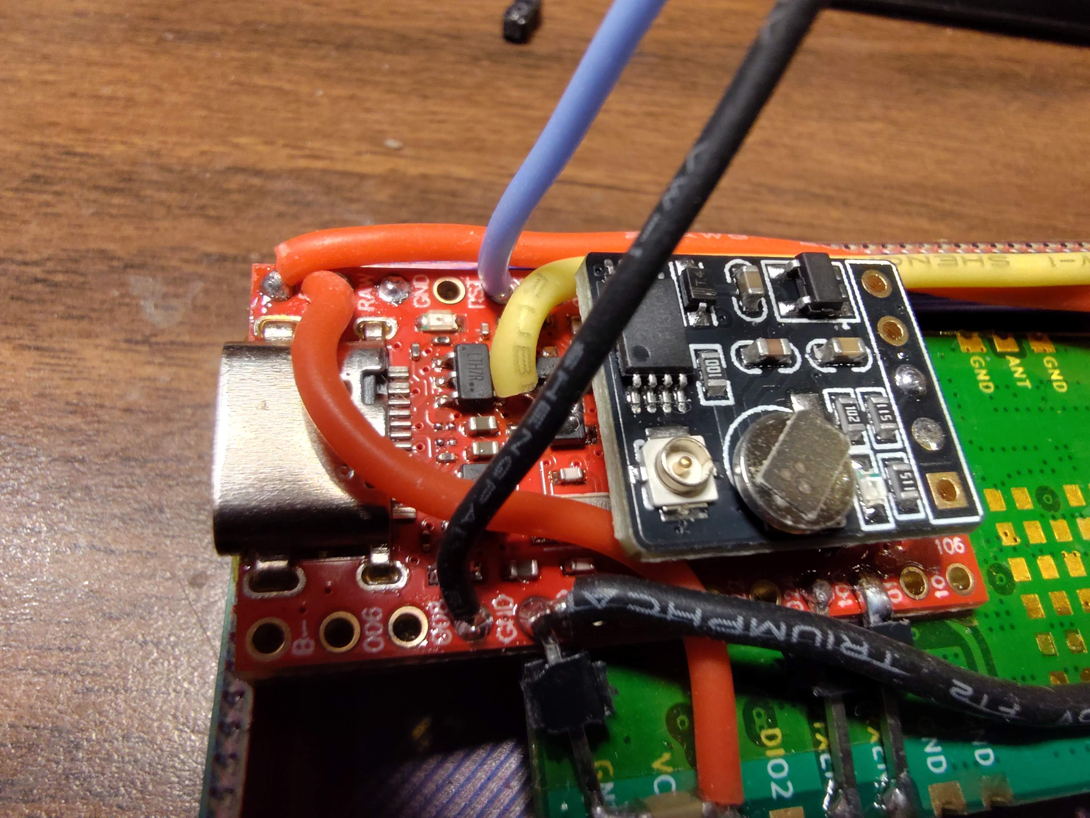
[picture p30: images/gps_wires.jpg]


Solder the GPS module in place and solder wires to connect the 3.3V
and GND pads from the NRF52840 module to the GPS module as shown.

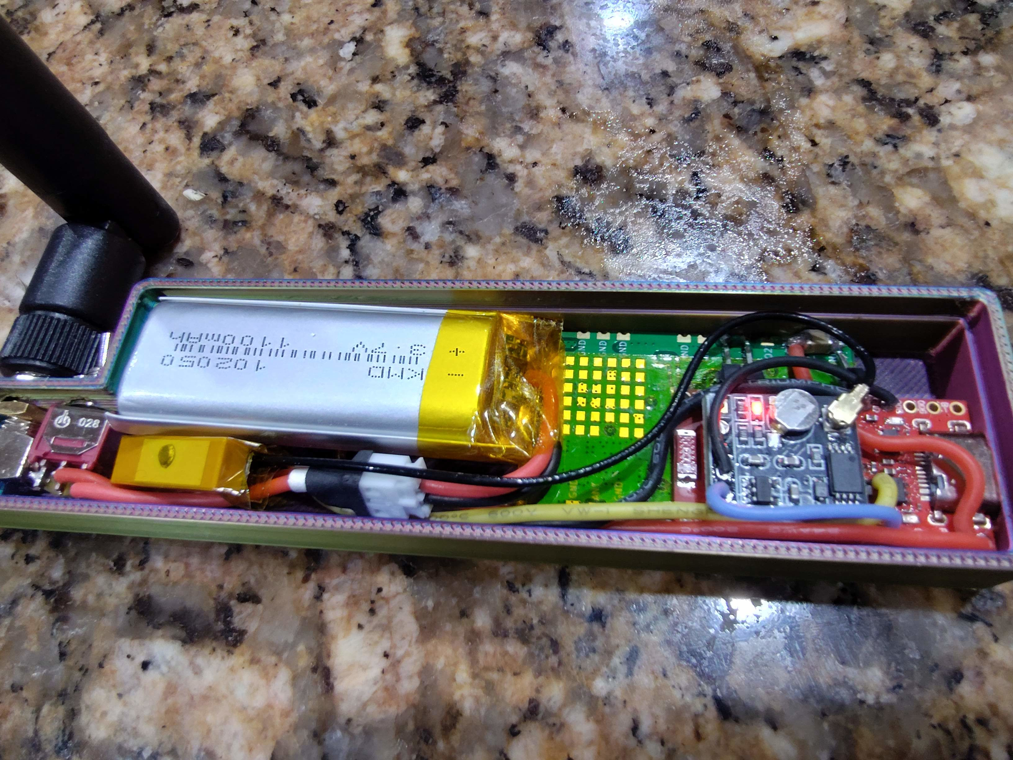
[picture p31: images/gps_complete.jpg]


Insulate the back and sides of the GPS antenna with tape and connect the U.FL.
Position it in the case as far away from the other boards as possible
so that it faces up and away from obstructions.  If you attach it with
double sided tape to the exposed portion of the E22 module, the extra
ground plane may help with reception.

### 19. Optional Passive Buzzer

The buzzer leads can be soldered directly to the output, P0.08 (+) and
a ground.  If you bend the negative pin, it can be soldered directly to
the USB connector housing; providing ground, correct placement and a good
mechanical attachment.

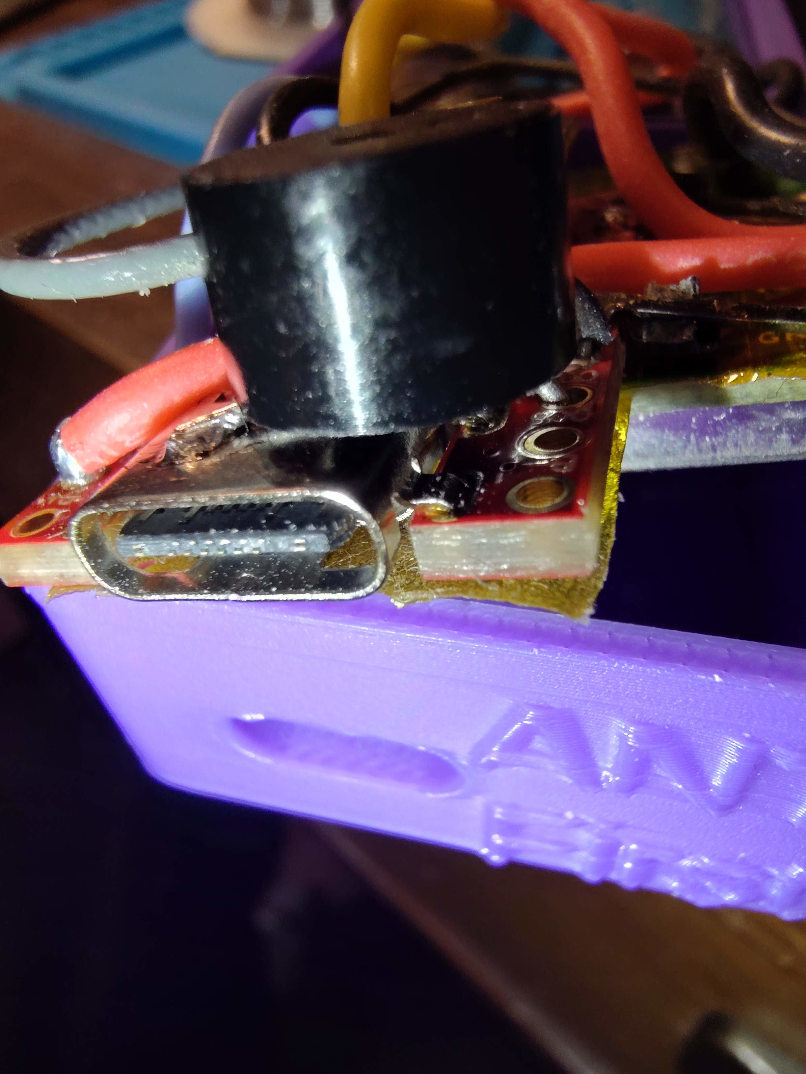
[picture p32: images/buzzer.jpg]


### 20. Optional Display

Solder 4 short light gauge wires from the appropriate display module
pads to ground, B+/raw, P1.04 (SDA), and P1.06 (SCL).  Power on and
test the display, then carefully place it in position on the corner
pegs on the inside of the lid with the top of the display towards the
longest edge.

Tape the display in place from the back with heat resistant tape, being
sure to cover the heat steaks.  Then while holding the display in
place, carefully apply heat with a very low temperature flat soldering tip to
melt the corner heat stake pegs and fasten the display to the lid.

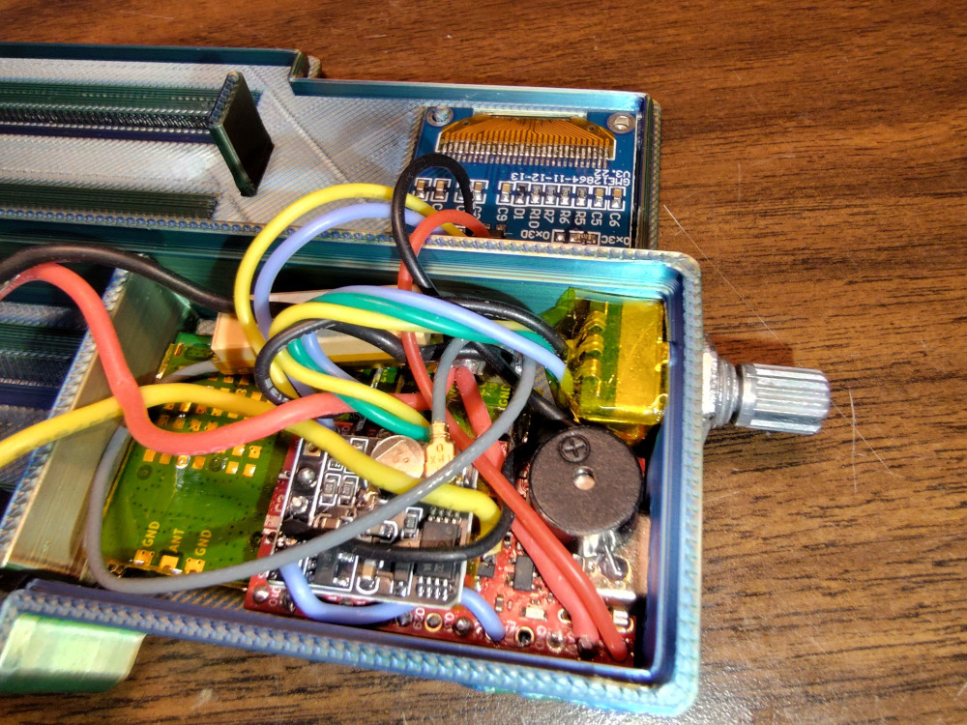
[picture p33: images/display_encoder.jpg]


### 21. Optional Rotary Encoder

Carefully bend the pins over the back of the plastic encoder body so
as to keep the pins where they exit the plastic as tight as possible
to allow them to fit in the case.

Strip a longer than normal portion of a short light gauge wire and solder it from
one pin on the 2 pin side to the middle pin on the 3 pin side and
continuing on to a ground pad on the NRF or E22 module.

Solder a wire from the remaining pin on the 2 pin side to P0.24.
Solder two wires from the remaining pins on the 3 pin side to
P0.20 (B) and P0.22 (A).

Ensure no pins are shorted except the two ground pins and cover the back
of the rotary encoder with tape.

Install the rotary encoder as shown above.

Enable the Canned Message module with Rotary encoder #1 enabled and
GPIO pin 22 and 20 for the A port and B port and GPIO pin 24 for the
Press port.

### 22. Assemble case

If you haven't already, slide the board assembly fully into place.

Carefully install the case lid, taking care not to pinch wires.  You
may want to use some tape to keep the longer wires in place at the
side of the case, away from the protruding parts of the lid.

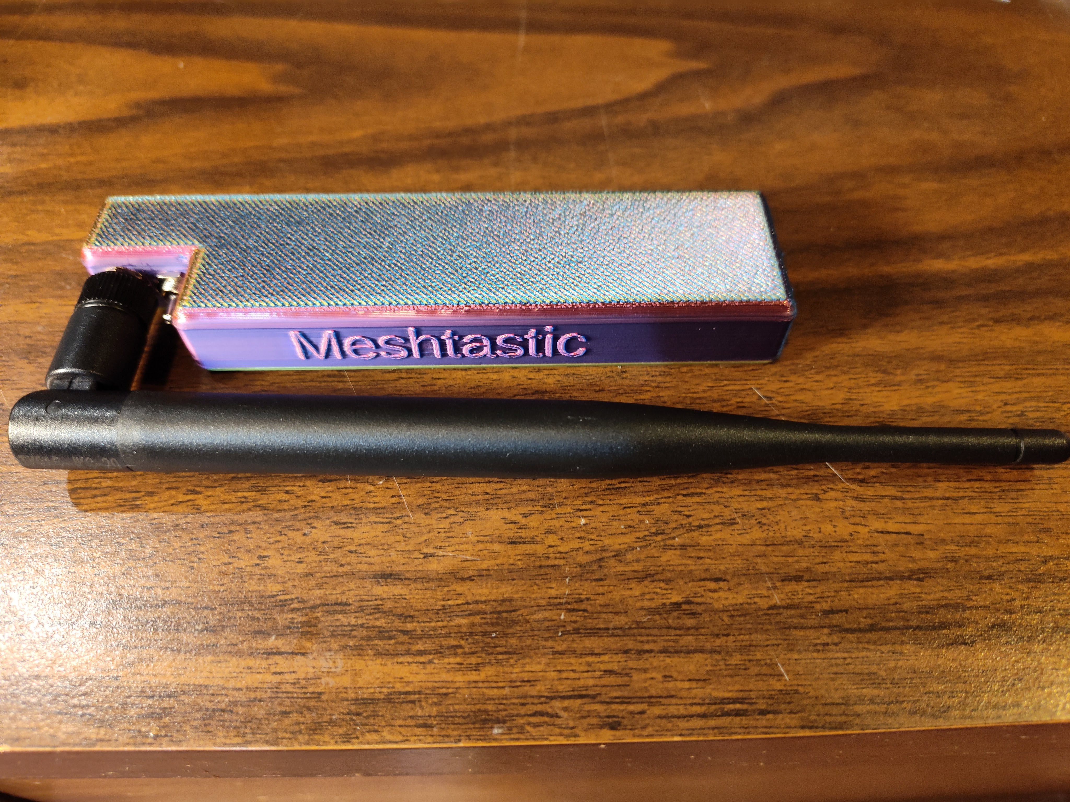
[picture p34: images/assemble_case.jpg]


### 23. Configure Meshtastic

In addition to the normal Region and LoRa preset, some hardware
features of this node need to be setup after the initial firmware
flash using the CLI or Meshtastic phone app:

- Voltage sense: Device configuration -> Power -> ADC multiplier override ratio

    For the recommended 10K to 1M ohm resistors, 2.0 should be close;
    for a more accurate reading, let the reported voltage stabilize
    for several minutes, then measure the battery voltage with a
    multi-meter and calculate a new ratio as 
    current_ratio * measured_voltage / reported_voltage

- Optional GPS: Device configuration -> Position -> Device GPS -> GPS Mode
  
    Set to "ENABLED" if you wish to use your GPS or "DISABLED" to save power
    
- Optional display and rotary encoder: Module configuration -> Canned Message

    Turn on "Rotary encoder #1 enabled"

    Set "GPIO pin for rotary encoder A port" to 22

    Set "GPIO pin for rotary encoder B port" to 20
    
    Set "GPIO pin for rotary encoder Press port" to 24
    
    Set "Generate input event on Press" to "SELECT"
    
    Set "Generate input event on CW" to "RIGHT"
    
    Set "Generate input event on CCW" to "LEFT"
    
    After saving the rotary encoder configuration, use the rotary
    encoder and display to select the "System" page, press the
    encoder and set "Notifications" to "Notifications" or
    anything other than "All enabled"; this will improve response
    time for the encoder by disabling buzzer sounds when the
    encoder is rotated.

## Usage notes:

If built as described here, this node can be powered by either USB or
the internal 1 S Lithium battery.

When the battery switch is on (towards the SMA jack), the battery is
connected to both the battery terminal of the NRF board and VCC of the
E22.  If the USB port is plugged in when the battery switch is on, the onboard
charger will charge a 1000 mAh battery in about 3 hours, assuming
you shorted the square pads as suggested.

When the battery switch is off (towards the case), the battery is
completely disconnected, and the USB voltage is connected to the B+ pad
and VCC of the E22.  This means that the battery will not charge with
the switch off, and that the node will operate only from USB power.

| Battery Switch | USB Power | Node On | Charging | TX Power |
| --- | --- | --- | --- | --- |
| On | Connected | ✅ | ✅ | ~1 watt  |
| Off | Connected | ✅ | ❌ | ~2 watts |
| On | Not connected | ✅ | ❌ | ~1 watt  |
| Off | Not connected | ❌ | ❌ | none |

> ⚠️ **Warning:** The antenna MUST be connected anytime
USB power is connected or the battery switch is on, including when charging, to
avoid damaging the E22 module.

When the antenna is installed, it
helps protect the battery switch from being inadvertently changed.  The 3D
design files include an optional safety device which, when screwed
onto the SMA jack, will prevent the battery switch from accidentally
being turned on. Use this in case you wish to carry the node with the
antenna detached.  If you really must charge the battery without an
antenna connected, connect a 50-ohm load.

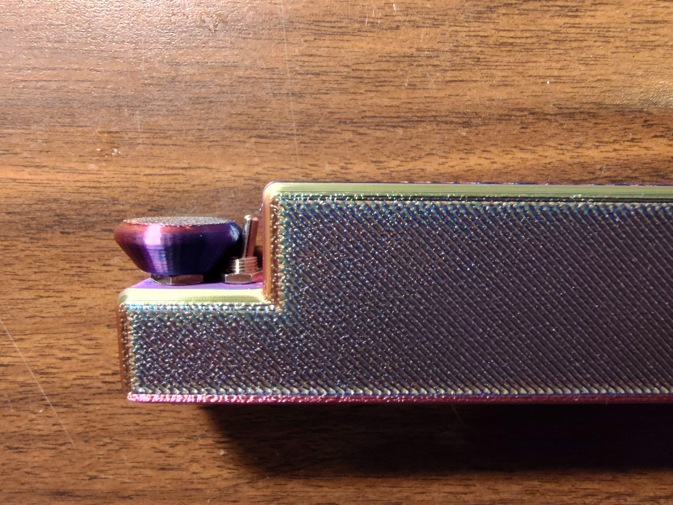
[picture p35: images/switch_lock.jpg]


When operating on battery power, the voltage supplied to the E22
module is between 4.2 and 3.0 volts.  The maximum output power of the
E22-900M33S will vary from about 1.2W to about 0.5W as the battery
voltage drops.

When operating on 5-volt USB power with the battery switch off, the E22-900m33S is
capable of a maximum output power of about 2 watts.  The Meshtastic firmware
variant `easy-nrf-pro-micro_e22` is configured to expect battery
voltage, thus, when powered via 5-volt USB, configuring the node for 30 dBm
(1 watt) output should produce about 33 dBm (2 watts).

Because they are designed for higher current applications, many cheap
battery protection boards are set to cut off at less than the safe
minimum of 3.0 volts.  To avoid damaging your battery or reducing its
service life, it is recommended to monitor the battery voltage and
turn off or charge your node before the battery is exhausted.

When charging, the blue LED will remain lit until the battery is 80-90%
charged. Then it will cycle on and off at various intervals while the
charge is completed and maintained.

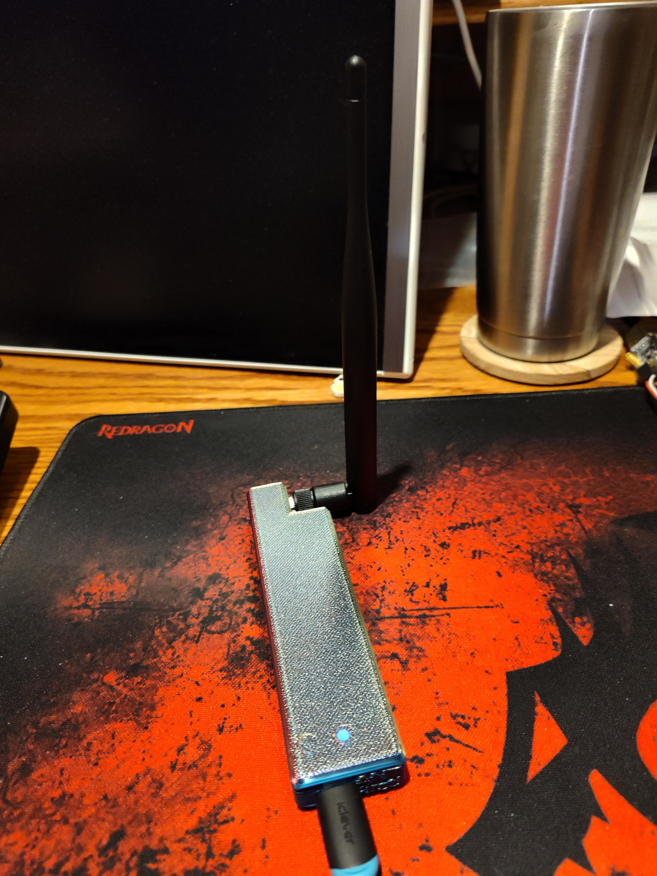
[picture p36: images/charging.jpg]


When running from battery power, the red LED closest to the USB
connector will periodically flash very briefly.  When running from USB
power, it will flash every 2 seconds.

If you installed and enabled the GPS, its LED will light while looking
for a fix.  It will flash at 1 Hz when a fix is obtained and turn off
when when idle.  Note that when the GPS is configured as "not
present", the power will remain on, but no fix will be used.  If you
install a GPS, be sure to enable or disable it.

## Technical notes:

This style of construction can also be used in a solar node.  The E22
ground plane does reduce the Bluetooth range and makes it more
directional which is usually not a problem for a pocket node, but if
you need to update a solar node OTA, you may want to remove the red
chip antenna and solder the coax to an external antenna in it's place.
Note that the second pad which the chip antenna is soldered to is not
a ground, so you will need to find another ground, perhaps by
carefully removing some solder mask from the ground plane in a
convenient location.

When used with a solar power manager which provides a 2 amp 5 volt
regulated output, you can connect it to the B+ pad.  In this case wire
the resistor voltage divider to the lithium battery positive terminal
instead of the B+ pad.

## Acknowledgments:

A big thank-you to Bob Van Valzah for testing the node and reviewing
and improving this document!

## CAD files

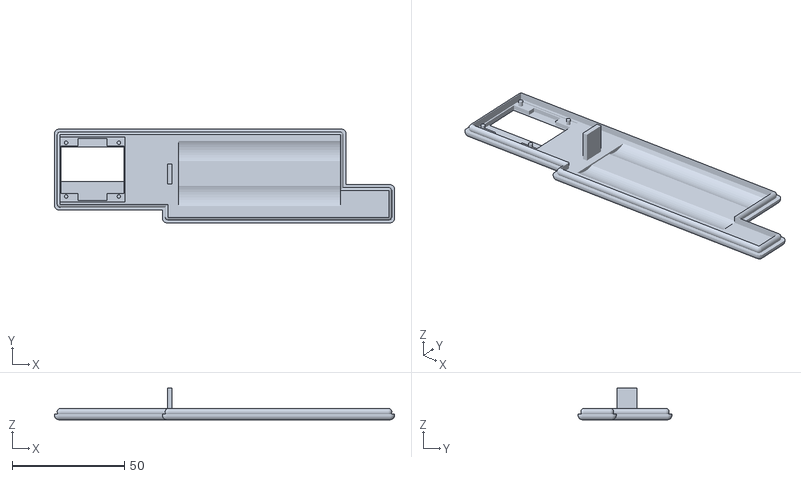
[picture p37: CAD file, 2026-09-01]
disp_top.stl
151.2 x 41.7 x 14.0

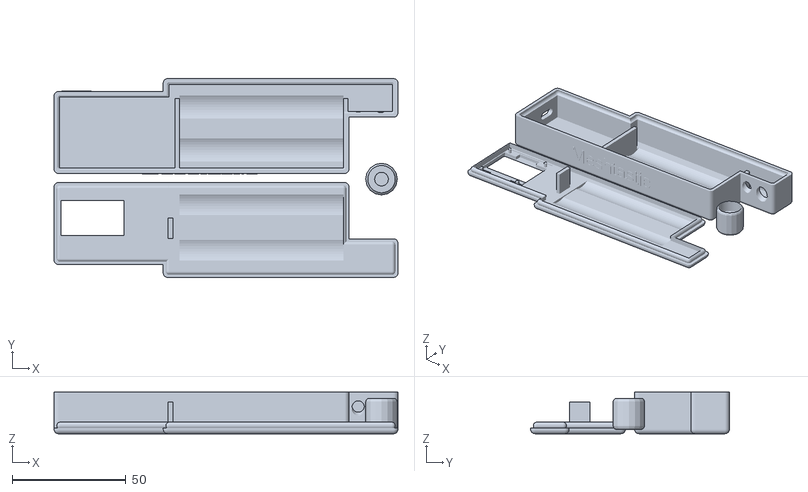
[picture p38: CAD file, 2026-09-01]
case_18650x2.stl
151.2 x 87.4 x 18.2

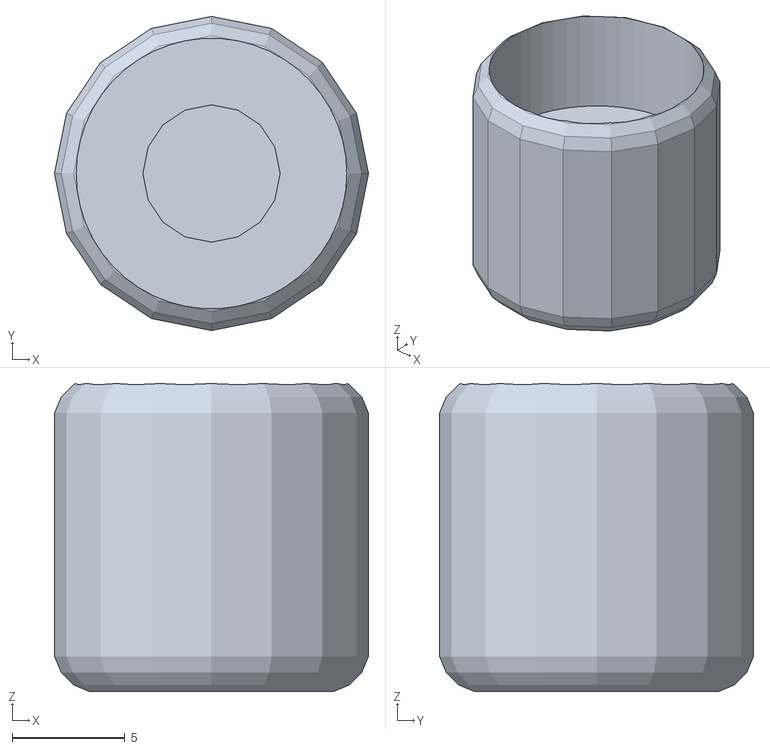
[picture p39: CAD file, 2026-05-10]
knob.stl
13.9 x 13.9 x 13.7

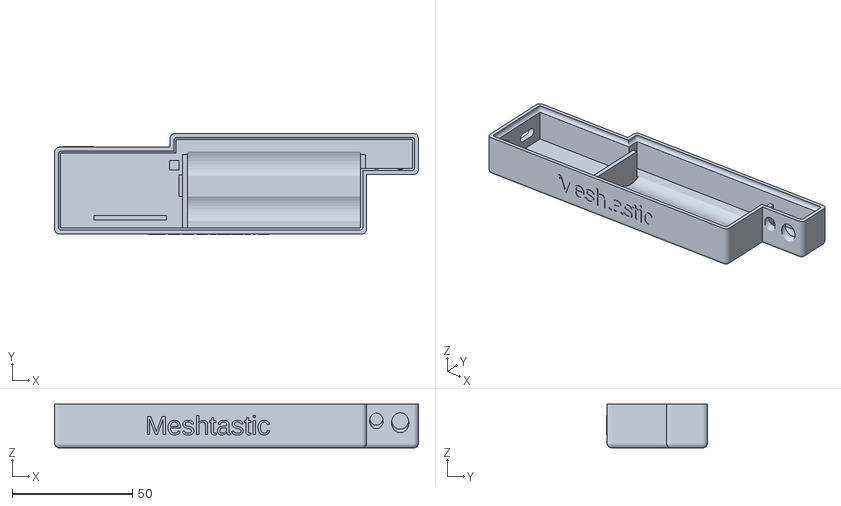
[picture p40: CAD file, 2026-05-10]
disp_bottom.stl
151.2 x 41.9 x 18.2

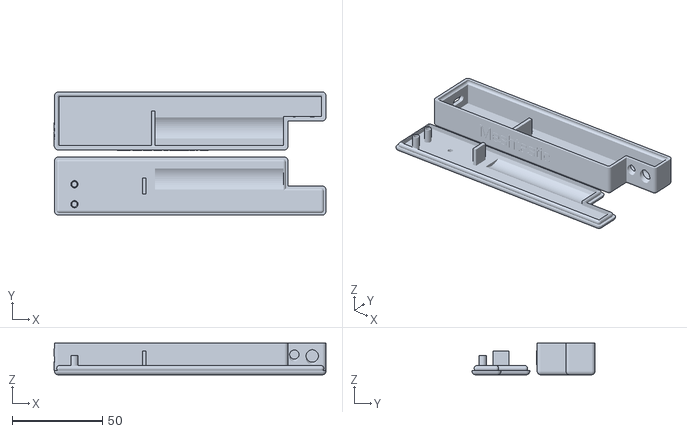
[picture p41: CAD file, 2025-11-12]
case_18650.stl
150.3 x 68.0 x 17.5

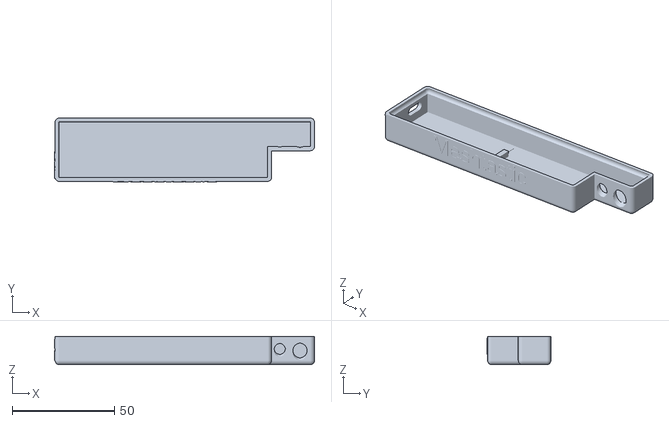
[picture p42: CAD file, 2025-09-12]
case_bottom.stl
127.3 x 31.2 x 13.8

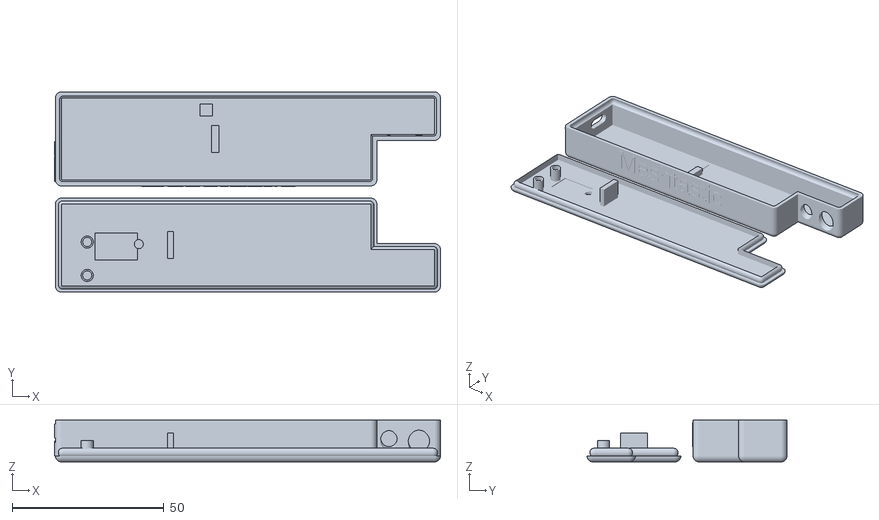
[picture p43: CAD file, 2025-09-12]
case_all.stl
127.3 x 66.0 x 13.8

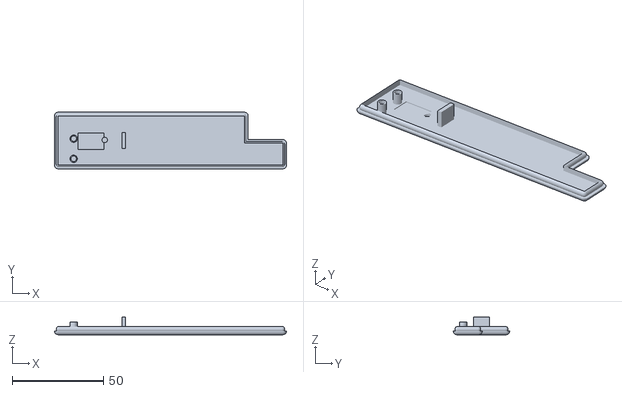
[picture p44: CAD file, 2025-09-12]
case_top.stl
127.0 x 31.0 x 9.60

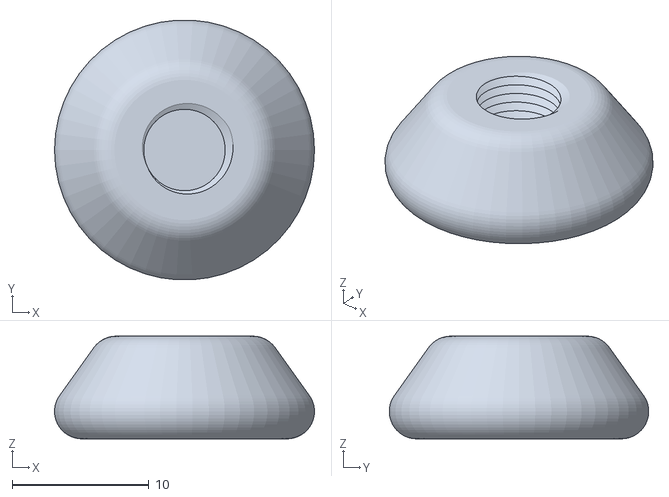
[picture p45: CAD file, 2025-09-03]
switch_lock.stl
19.0 x 19.0 x 7.49

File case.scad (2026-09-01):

/*
  Case with snap-on top for easy-nrf52-pro-micro_e22 DIY Meshtastic pocket node
  Copyright (c) 2026 Bradley Bosch
  This prints and fits well for me, but may still needs some parameterization improvement.
  If you change a parameter, you might want to double check it didn't have an unexpected
  effect before you print.
*/
$fn = 50; // Change default faces to something reasonable
top=0.0;
thick=5; // The case walls are thick/2 thick; 4..5 works well
diameter=4; // diameter of curved corners.  Bug: other things may depend on this
extra_tight=.1; // must be > 0; increase for tighter lid
// increasing these next two very much is likely to interfere with holes
lid_d=3; // diameter of cover snap curve; increase for tighter lid
ledge=lid_d+.1; // depth of ledge
ledge_off=lid_d/6; // decrease for tighter lid
box_h=11.8; // lipo battery + sma coax thickness  // 1000 mAh cell
stay_height=4.2; // height of E22 with tape
ant_x=19.5 + diameter;
ant_y=12;
n_batt = 2; // Number of 18650 cells 0 for lipo, 1, or 2
display=true; // add display and rotary encoder
boards_y=31; // 27 minimum; increase this for more GPS or encoder space or if antenna cable won't qute reach
boards_x=(n_batt > 1) ? 48: 0; // decrease for more room for wires to enter electronics section
mount_x=49.2;
mount_w=2.0;
mount_h=2.75;
sma_d=7.2; // SMA and encoder hole diameter
switch_d=7;
switch_hole=5.6;
switch_loc=1.0;
usb_h=3.8;
usb_l=2.0;
usb_w=9.4;
usb_y=-5.1;
usb_z=6;
wires_y=(n_batt > 1) ? 7: 0;
batt_l=(n_batt > 0) ? 72.0: 48;
batt_d=(n_batt > 0) ? 18.75: 0;
box_y=(n_batt > 1) ? batt_d * n_batt-.8: boards_y; // subtract less to increase wire space
box_x=mount_x+batt_l+mount_w+1.5-boards_x;
batt_x=mount_w/2+mount_x-box_x/2+mount_w/2+1.5;
batt_y=-(box_y - batt_d)/2;
batt_z=0;

knob_length=14;
knob_width=14;
knob_inner_hole=6.09;
knob_outer_hole=12;
knob_inner_depth=6;

box_z = (n_batt > 0) ? batt_d - thick + 2 : box_h;

pipe_length=box_z - 6.8; // MCU LED light pipe

module inside() {
        // hollow inside
        translate([0,0,0]) {
            cube([box_x,box_y,box_z],center = true);
            translate([(box_x+(ant_x - diameter))/2,(box_y-ant_y)/2,0])
                cube([ant_x+.001,ant_y,box_z+.001],center = true);
            translate([-(box_x + (boards_x ))/2+.001,-(box_y-boards_y)/2,0])
                cube([boards_x+.001,boards_y,box_z+.001],center = true);
        }   
        // battery space
        if (n_batt > 0) { // 18650
            translate([batt_x-boards_x,batt_y-(thick-2)/2,batt_z]) {
                rotate([0,90,0])
                    cylinder(batt_l, d=batt_d, center=false);
            }
        }
        if (n_batt > 1) { // 18650
            translate([batt_x-boards_x,batt_y+batt_d-(thick-2)/2,batt_z]) {
                rotate([0,90,0])
                    cylinder(batt_l, d=batt_d, center=false);
            }
            // A little extra off the top to accomodate battery protection
            translate([batt_x-boards_x,batt_y,batt_z+batt_d/2-thick*2/3]) {
                cube([batt_l, batt_d, thick/2], center=false);
            }
        }
}

module bottom(extra=0) {
    difference () {

        minkowski() {
            union() {
                translate([(box_x + (ant_x - diameter))/2-.001,(box_y-ant_y)/2,0])
                cube([ant_x+thick-diameter,ant_y+thick-diameter,box_z+thick-diameter],center = true);
                translate([-(box_x + (boards_x))/2+.001,-(box_y-boards_y)/2,0])
                cube([boards_x+thick-diameter,boards_y+thick-diameter,box_z+thick-diameter],center = true);
                cube([box_x+thick-diameter,box_y+thick-diameter,box_z+thick-diameter],center = true);
            }
            sphere(d=diameter+extra);
        }

        // chopp off top
        translate([0,0,box_z-top]) cube([(box_x+thick+diameter+ant_x)*2,box_y+thick+diameter*2+1,box_z],center = true);

        // cut out ledge for snap lid
        translate([0,0,box_z/2-top-ledge/2+ledge_off]) {
            minkowski() {
                union() {
                    cube([box_x+thick/2-lid_d+extra,box_y+thick/2-lid_d+extra,ledge-lid_d],center = true);
                    translate([(box_x+(ant_x - diameter))/2,(box_y-ant_y)/2,0])
                    cube([ant_x+thick/2-lid_d+extra,ant_y+thick/2-lid_d+extra,ledge-lid_d],center = true);
                    translate([-(box_x + (boards_x))/2+.001,-(box_y-boards_y)/2,0])
                    cube([boards_x+thick/2-lid_d+extra,boards_y+thick/2-lid_d+extra,ledge-lid_d],center = true);
                }
                sphere(d=lid_d);
            }
        }
        inside();
    }
}

module top() {
    rotate([180,0,0])  {
        difference () {

            minkowski() {
                union() {
                    translate([(box_x+(ant_x - diameter))/2,(box_y-ant_y)/2,0])
                    cube([ant_x+thick-diameter,ant_y+thick-diameter,box_z+thick-diameter],center = true);
                    translate([-(box_x + (boards_x))/2+.001,-(box_y-boards_y)/2,0])
                    cube([boards_x+thick-diameter,boards_y+thick-diameter,box_z+thick-diameter],center = true);
                    cube([box_x+thick-diameter,box_y+thick-diameter,box_z+thick-diameter],center = true);
                }
                sphere(d=diameter);
            }

            // reverse ledge
            bottom(extra=extra_tight);

            // chopp off bottom
            translate([0,0,-top-ledge+ledge_off]) cube([(box_x+thick+diameter+ant_x)*2,box_y+thick+diameter+1,box_z],center = true);

            inside();

            // led holes
            if (! display) {
                translate([-box_x/2-boards_x + 8.5, boards_y - box_y/2 - 3.5, box_z/2])
                    #cylinder(thick-.4, d=3, center=true);
                    translate([-box_x/2-boards_x + 8.5, boards_y - box_y/2 -14.5, box_z/2])
                    #cylinder(thick-.4, d=3, center=true);
                    translate([-box_x/2-boards_x + 25.5, boards_y - box_y/2 - 13.8, box_z/2])
                    #cylinder(thick-.4, d=3, center=true);
            }
            // space for GPS
            if (box_z < 13)
            translate([-box_x/2-boards_x + 18, boards_y - box_y/2 - 13, box_z/2+thick/4-1.5])
                #cube ([14,9,thick/2], center=true);
            // display hole
            if (display) {
                translate([-box_x/2-boards_x + 28.8/2, (boards_y-box_y)/2 - 2.4, box_z/2+thick/4])
                    cube([27.8,15.5,thick/2], center=true);
                translate([-box_x/2-boards_x + 28.8/2, (boards_y-box_y)/2+.1, box_z/2+thick/4-.4])
                    cube([27.8,21,thick/2], center=true);
                translate([-box_x/2-boards_x + 28.8/2, (boards_y-box_y)/2, box_z/2+thick/4-.4])
                    cube([13,27.5,thick/2], center=true);
                translate([-box_x/2-boards_x + 28.8/2, (boards_y-box_y)/2, box_z/2+thick/4-2.1])
                    cube([28.8,28.8,thick/2], center=true);
            }
        }
        if (!display) {
            // led light guides
            difference () {
                translate([-box_x/2-boards_x + 8.5, boards_y - box_y/2 - 3.5, box_z/2-pipe_length/2])
                    cylinder(pipe_length, d=4, center=true);
                translate([-box_x/2-boards_x + 8.5, boards_y - box_y/2 - 3.5, box_z/2-pipe_length/2-.001])
                    #cylinder(pipe_length, d=3, center=true);
                    }
            difference () {
                translate([-box_x/2-boards_x + 8.5, boards_y - box_y/2 - 14.5, box_z/2-pipe_length/2])
                    cylinder(pipe_length, d=4, center=true);
                translate([-box_x/2-boards_x + 8.5, boards_y - box_y/2 - 14.5, box_z/2-pipe_length/2-.001])
                    #cylinder(pipe_length, d=3, center=true);
                    }
        } else {
            // display posts 
            translate([-box_x/2-boards_x + 28.8/2+11.75, (boards_y-box_y)/2+11.95, box_z/2+thick/4-3])
                cylinder(3, d=1.6);
            translate([-box_x/2-boards_x + 28.8/2-11.75, (boards_y-box_y)/2+11.95, box_z/2+thick/4-3])
                cylinder(3, d=1.6);
            translate([-box_x/2-boards_x + 28.8/2+11.75, (boards_y-box_y)/2-11.95, box_z/2+thick/4-3])
                cylinder(3, d=1.6);
            translate([-box_x/2-boards_x + 28.8/2-11.75, (boards_y-box_y)/2-11.95, box_z/2+thick/4-3])
                cylinder(3, d=1.6);
        }
        // stay to keep boards in place
        translate([mount_w/2+mount_x-box_x/2-boards_x-1.5, boards_y-27-box_y/2+13.5, stay_height/2-0.001]) cube([2, 9, box_z-stay_height], center=true);
    }
}
module usb() {
    translate([0, -usb_l, -box_z/2])
        rotate([0,90,0])
        hull() {
        cylinder(thick+1, d=usb_h);
        translate([0,usb_w-usb_h,0]) cylinder(thick+1, d=usb_h);
    }
}
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

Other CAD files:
threads.scad

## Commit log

2025-07-29 Draft easy_E22 project documentation and support files
    [case.scad, case_all.stl, case_bottom.stl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]
2025-07-31 Move parts photo
    [case.scad]
2025-08-07 Add antenna supplier link
2025-08-14 Clarify the ground connection
2025-09-03 Minor updates and improvements
    [case.scad, case_all.stl, case_bottom.stl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]
2025-09-12 Case and instruction refinements based on 3rd build
    [case.scad, case_all.stl, case_bottom.stl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]
2025-09-15 GPS LED
2025-10-30 Minor improvements to case Add note on filter capacitor
    [case.scad]
2025-11-06 Oops, back to lipo size case
    [case.scad]
2025-11-12 Add a version of the case to fit a protected 18650 battery for up to 1 week battery life.
    [case.scad, case_18650.stl]
2025-11-12 Add estimated battery life for 18650 battery
2025-11-18 First pass dual 18650 cell version
    [case.scad]
2025-11-22 Updated 18650x2 case
    [case.scad, case_18650x2.stl]
2026-05-10 Add optional buzzer, OLED display and rotary encoder
    [case.scad, disp_bottom.stl, disp_top.stl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]
2026-09-01 Allow a little room for battery protection on 18650x2 case Add firmware build instructions Add battery pack construction details Add initial meshtastic configuration instructions General README.md im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
    [case.scad, case_18650x2.stl, disp_top.stl]
2026-09-01 Oops, wrong battery pack image
